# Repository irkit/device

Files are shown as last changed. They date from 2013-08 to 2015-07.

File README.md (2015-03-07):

IRKit Device
===

IRKit device and [IRKit SDK](https://github.com/irkit/ios-sdk) lets you control your home electronics from your iOS and Android devices.
IRKit device has a Infrared LED and receiver, and a WiFi module inside.
Internet connected devices can make IRKit send IR signals for you.

## Get IRKit Device

In Japan: [amazon.co.jp](http://www.amazon.co.jp/gp/product/B00H91KK26)  
World wide shipping available: [switch-science](https://international.switch-science.com/catalog/1644/)

## Schematics

Basically, it's a [Arduino Leonardo](http://arduino.cc/en/Main/ArduinoBoardLeonardo) fork with following modifications:

* added a [WiFi module](http://www.gainspan.com/gs1011mips) ( [GainSpan](http://www.gainspan.com/home) 's WiFi module ).
* added Infrared Receiver, Infrared LED and some LEDs.



## Firmware

It's basically a normal Arduino sketch.

See [IRKit.ino](https://github.com/irkit/device/blob/master/firmware/src/IRKit/IRKit.ino)

## Board

### Top



### Bottom



## Case

See [Case](https://github.com/irkit/device/tree/master/case)

## Extend it!

Following Arduino pins are pulled out for you.

* D2,D3,D4,D5,D12,TXLED
* A0,A1,A2,A3

See [IRKit.sch, eagle schematic file](https://github.com/irkit/device/blob/master/hardware/IRKit.sch) 's CN2

## How to update firmware

You can use [Arduino IDE](http://arduino.cc/en/Main/Software) to write IRKit's firmware.  
Follow this procedure (for MacOS).

1. Download, install and run [Arduino IDE](http://arduino.cc/en/Main/Software)
1. Connect IRKit using USB Micro-B cable to Mac.
1. Navigate to Arduino IDE Menu and select Tools -> Board -> "Arduino Leonardo".
1. Navigate to Arduino IDE Menu and select Tools -> Serial Port -> "/dev/tty.usbmodemXXXX".

   XXXX part should differ on your environment.

1. Download latest zip file from [IRKit device tags](https://github.com/irkit/device/releases).
1. Unzip it and open `firmware/src/IRKit/` directory.
1. Rename `version.template` to `version.c` .

   FYI. Product version is embedded here in official builds.

1. Double click `IRKit.ino` in the same directory.
1. Navigate to Arduino IDE Menu and click File -> Upload, to write into IRKit.
1. All Done!

### Example fork of IRKit firmware

[@acourreges](https://github.com/acourreges) created a branch [settings-led-cloud](https://github.com/acourreges/device/tree/settings-led-cloud/firmware) that enables you to configure:  
* Status LED behaviour (you might want to turn the LED off when the device is idle?)
* Enable/Disable cloud control (you might want IRKit not to connect to Internet?)

See [config.h](https://github.com/acourreges/device/blob/settings-led-cloud/firmware/src/IRKit/config.h) for details.

## How to get logs

IRKit logs what it's doing to USB serial, and you can use [Arduino IDE](http://arduino.cc/en/Main/Software) to see it.  
Follow this procedure (for MacOS).

1. Download, install and run [Arduino IDE](http://arduino.cc/en/Main/Software)
1. Connect IRKit using USB Micro-B cable to Mac.
1. Navigate to Arduino IDE Menu and select Tools -> Serial Port -> "/dev/tty.usbmodemXXXX".

   XXXX part should differ on your environment.

1. Navigate to Arduino IDE Menu and select Tools -> Serial Monitor.
1. Change new window's right-bottom settings to "No line ending" and "115200 baud", and close the window.
1. Reconnect IRKit and immediately start Serial Monitor again.

   This is to collect logs as soon as IRKit startups.

1. Copy and send logs to IRKit developer, thanks!

## ファームウェアアップデート方法

IRKitのファームウェアは、 [Arduino IDE](http://arduino.cc/en/Main/Software) を使って書き込むことができます。

出荷時のファームウェアバージョンによって、どのファームウェアバージョンまでアップデートできるかが変わります。  
以下の手順で現在のバージョンを確認し、対応するバージョンを使用してください。

| 現在のバージョン | 対応する最新のバージョン |
| --- | --- |
| 1.3.3以下 | [1.3.3](https://github.com/irkit/device/releases/tag/v1.3.3) |
| 1.3.4以上 | [最新](https://github.com/irkit/device/releases/latest) |

[IRKitシンプルリモコン](https://itunes.apple.com/us/app/irkit-simple-remote/id778790928?l=ja&ls=1&mt=8) を起動し、左上のボタンから設定画面を開くと、以下の画像の赤の四角のようにファームウェアバージョンを表示します。

<a href="https://www.flickr.com/photos/99687464@N00/14023119426" title="IRKit-firmware-version">IRKit-firmware-version</a>

以下がファームウェアのアップデート方法です(MacOS編)。

1. [Arduino IDE](http://arduino.cc/en/Main/Software) をダウンロードしてインストール後、起動します。
1. IRKitをUSB Micro-Bケーブルを使ってMacに接続します。
1. Arduino IDEのメニューから ツール -> マイコンボード -> "Arduino Leonardo" を選びます。
1. Arduino IDEのメニューから ツール -> シリアルポート -> "/dev/tty.usbmodemXXXX" を選びます。

   環境によってXXXXの部分やその前後が異なる場合があります。

1. ファームウェアをダウンロードし、zipファイルを解凍します。
1. 解凍したディレクトリ内にある `firmware/src/IRKit/` ディレクトリを開きます。
1. 同ディレクトリ内の `version.template` を `version.c` にリネームします。  

   参考) 製品版ではIRKitのバージョン情報をここに埋め込んでいます。

1. 同ディレクトリ内の `GSwifi.cpp` 内に埋め込んであるWi-Fiアクセスポイントのパスワードを書き換えます。  

   https://github.com/irkit/device/blob/master/firmware/src/IRKit/GSwifi.cpp#L1096  
   の `XXXXXXXXXX` を任意の文字列に書き換えてください。  
   参考) IRKitの出荷前に書き換えてから出荷しています。

1. 同ディレクトリ内の `IRKit.ino` をダブルクリックして Arduino IDE で開きます。
1. Arduino IDEのメニューから ファイル -> マイコンボードに書き込む を押してIRKitに書き込みます。
1. 完了！

### プログラムメモリについて

IRKitのマイコン ATmega32U4 はプログラムメモリを 32kB 積んでいますが、  
IRKitのファームウェアでそのほぼ全てを使用しています。

ファームウェアに改造を行い、機能追加する場合には、  
不必要な機能のログ出力や機能自体を削ってください。

[log.hの22-26行目](https://github.com/irkit/device/blob/master/firmware/src/IRKit/log.h#L22) 辺りをコメントアウトすることで、ログ出力を止めることができます。

### IRKitファームウェアのFork例

[@acourreges](https://github.com/acourreges)の[settings-led-cloud](https://github.com/acourreges/device/tree/settings-led-cloud/firmware)では、以下を変更可能にしています。  
* ステータスLEDの動作 (赤外線を送受信していない時にはLEDを消灯しておきたい??)
* クラウドとの接続を有効/無効 (IRKitをインターネットに接続せずに使いたい??)

詳しくは [config.h](https://github.com/acourreges/device/blob/settings-led-cloud/firmware/src/IRKit/config.h) を見てください。

[@shokai](https://github.com/shokai)の[tempe_sensor](https://github.com/shokai/irkit-device/compare/master...tempe_sensor)ブランチ、[sensors_json](https://github.com/shokai/irkit-device/compare/master...sensors_json)ブランチでは、  
温度センサからの入力、アナログピンの値を読み、IRKit内蔵のWebサーバからHTTP GETで取得できるようにしています。

詳しくは [IRKitのファームウェアを改造して温度センサーを追加した](http://shokai.org/blog/archives/8802) をご覧ください。

## ログ取得方法

IRKitは、USB Micro-Bを使いパソコンまたはMacに接続すると、動作ログを取得することができます。  
以下の手順でログを取得します(MacOS編)。

1. [Arduino IDE](http://arduino.cc/en/Main/Software) をダウンロードしてインストール後、起動します。
1. IRKitをUSB Micro-Bケーブルを使ってMacに接続します。
1. Arduino IDEのメニューから ツール -> シリアルポート -> "/dev/tty.usbmodemXXXX" を選びます。

   環境によってXXXXの部分やその前後が異なる場合があります。

1. Arduino IDEのメニューから ツール -> シリアルモニタ を選びます。
1. 新しく開いたウィンドウの右下の設定を "改行なし" "115200baud" に変更し、一度ウィンドウを閉じます。
1. IRKitのUSB Micro-Bケーブルを外し、再度接続した直後に、上記同様に シリアルモニタ を開きます。

   IRKit起動直後からのログを取得するためです。

1. ウィンドウに表示される文字列をコピーして開発者へメールしてください。ありがとうございます！

## License

Firmware is licensed under GPLv2 or later.  
See details in [firmware/LICENSE](https://github.com/irkit/device/blob/master/firmware/LICENSE).

Schematics are licensed under Creative Commons Attribution Share-Alike license.  
See details in [hardware/LICENSE](https://github.com/irkit/device/blob/master/hardware/LICENSE).

Case is licensed under Creative Commons Attribution NonCommercial Share-Alike license.  
See details in [case/LICENSE](https://github.com/irkit/device/blob/master/case/LICENSE).

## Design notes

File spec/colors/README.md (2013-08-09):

Full Color LED Spec
===================

## Color/State Map

* Started, Unconnected         : Green
* Connected and Authorized     : Blue
* Connected and Non Authorized : Yellow Blink
* Bluetooth -> IR              : Blue Blink
* IR -> Bluetooth              : Cyan Blink
* Timeout                      : Red

## Available Colors

* Red
* Green
* Blue
* Cyan
* Magenta
* Yellow
* White
* Off

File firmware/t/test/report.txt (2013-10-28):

* flash memory
** base 4270
#include "Arduino.h"
#include "pgmStrToRAM.h"

void setup() {
    // USB serial
    Serial.begin(115200);

    // wait for leonardo
    while ( ! Serial );
}

void loop() {
}

** overload Serial.print 6452
#include "Arduino.h"
#include "pgmStrToRAM.h"

void setup() {
    // USB serial
    Serial.begin(115200);

    // wait for leonardo
    while ( ! Serial );

    Serial.print(3);
    Serial.print(3.14);
}

void loop() {
}
** only Serial.print(float) 6398
#include "Arduino.h"
#include "pgmStrToRAM.h"

void setup() {
    // USB serial
    Serial.begin(115200);

    // wait for leonardo
    while ( ! Serial );

    Serial.print(3.14);
}

void loop() {
}
** only Serial.print(int) 4838
#include "Arduino.h"
#include "pgmStrToRAM.h"

void setup() {
    // USB serial
    Serial.begin(115200);

    // wait for leonardo
    while ( ! Serial );

    Serial.print(3);
}

void loop() {
}
** only Serial.print(char*) 4344
#include "Arduino.h"
#include "pgmStrToRAM.h"

void setup() {
    // USB serial
    Serial.begin(115200);

    // wait for leonardo
    while ( ! Serial );

    Serial.print("3");
}

void loop() {
}

** only Serial.print(char) 4296
#include "Arduino.h"
#include "pgmStrToRAM.h"

void setup() {
    // USB serial
    Serial.begin(115200);

    // wait for leonardo
    while ( ! Serial );

    Serial.print('3');
}

void loop() {
}

** sprintf 6666
#include "Arduino.h"
#include "pgmStrToRAM.h"
#include "tinyprint.h"

void setup() {
    // USB serial
    Serial.begin(115200);

    // wait for leonardo
    while ( ! Serial );

    // Serial.print("3");
    tinyprint_int(3);
}

void loop() {
}
--- tinyprint.cpp
#include "Arduino.h"
#include "tinyprint.h"
#include "pgmStrToRAM.h"

size_t tinyprint_int(int n) {
    // -32767 - 32767
    char tmp[7];
    sprintf( tmp, P("%d"), n );
    return Serial.print( tmp );
}

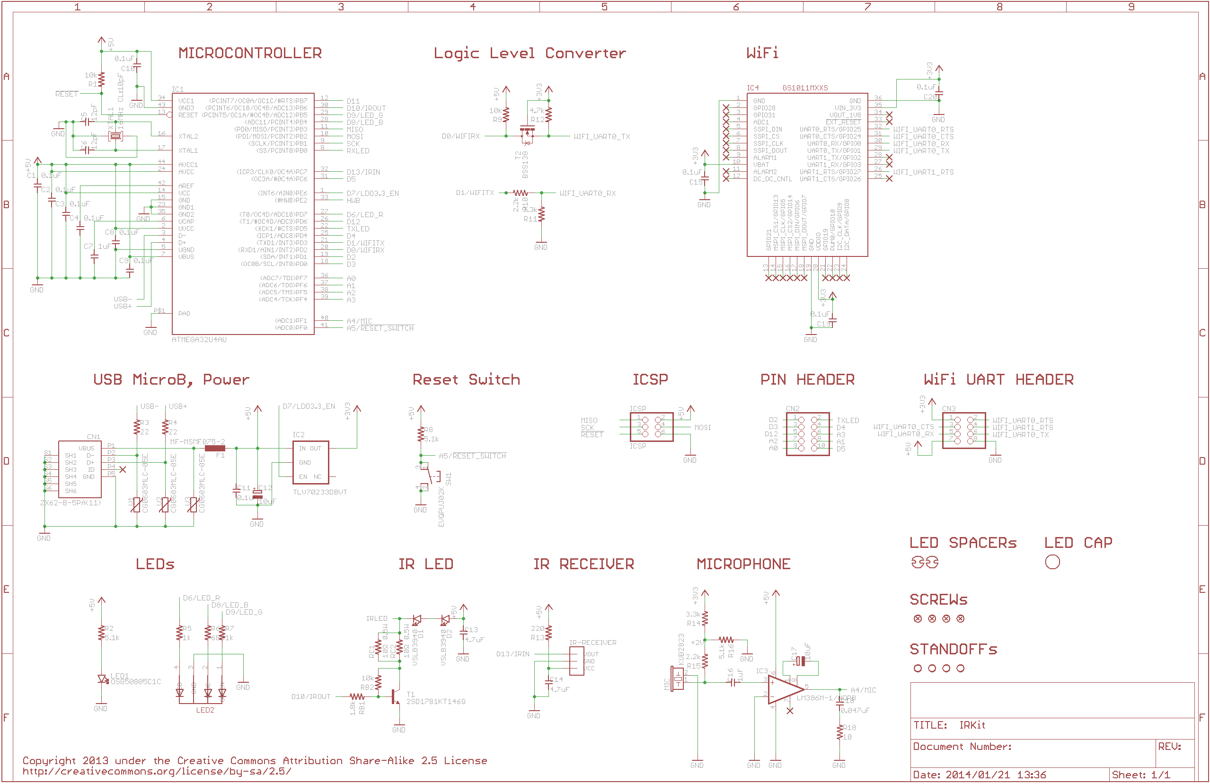
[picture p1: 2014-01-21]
hardware/schematic.png

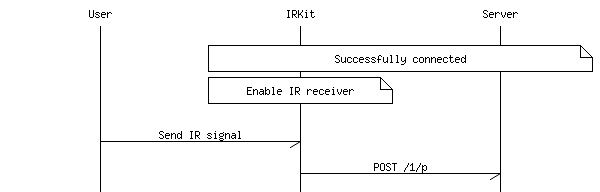
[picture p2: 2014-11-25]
spec/diagrams/ir-learn.png

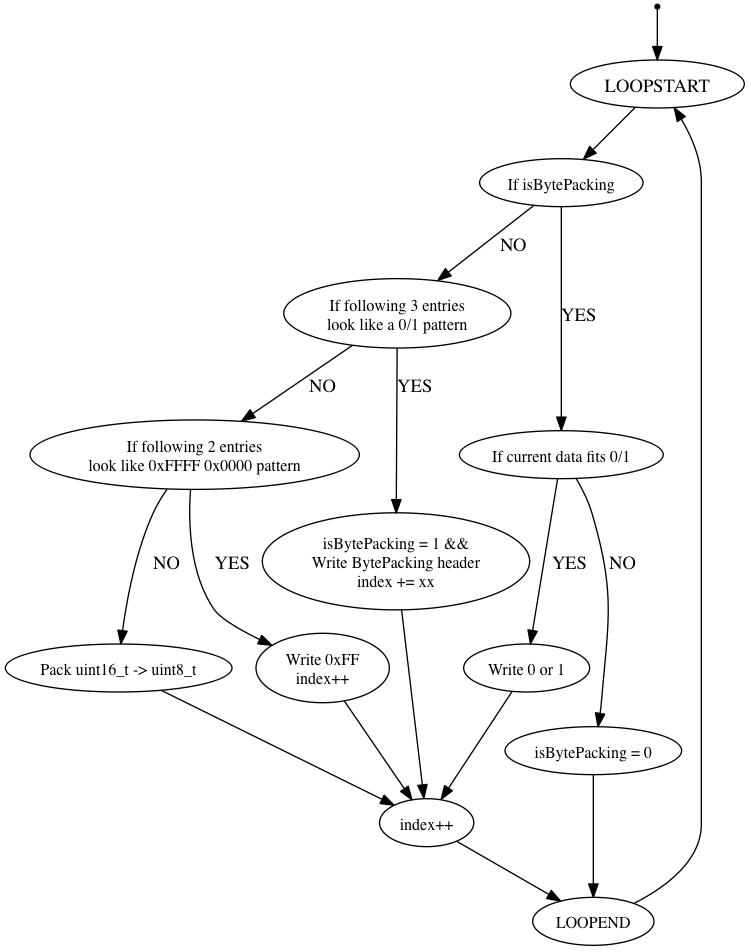
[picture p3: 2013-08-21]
spec/diagrams/packer.png

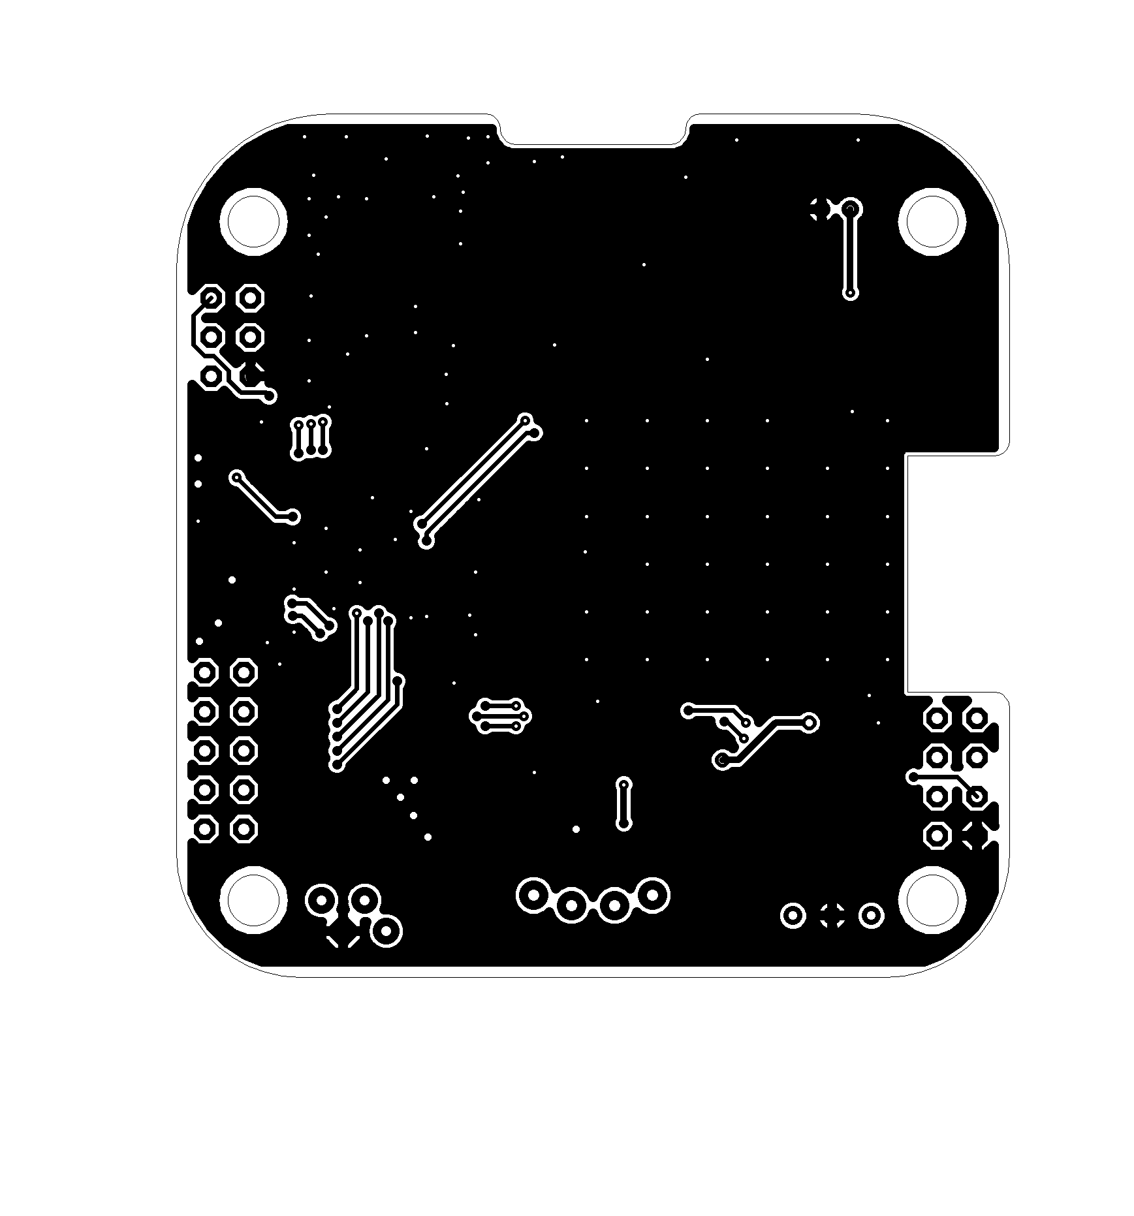
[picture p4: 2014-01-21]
hardware/bottom.png

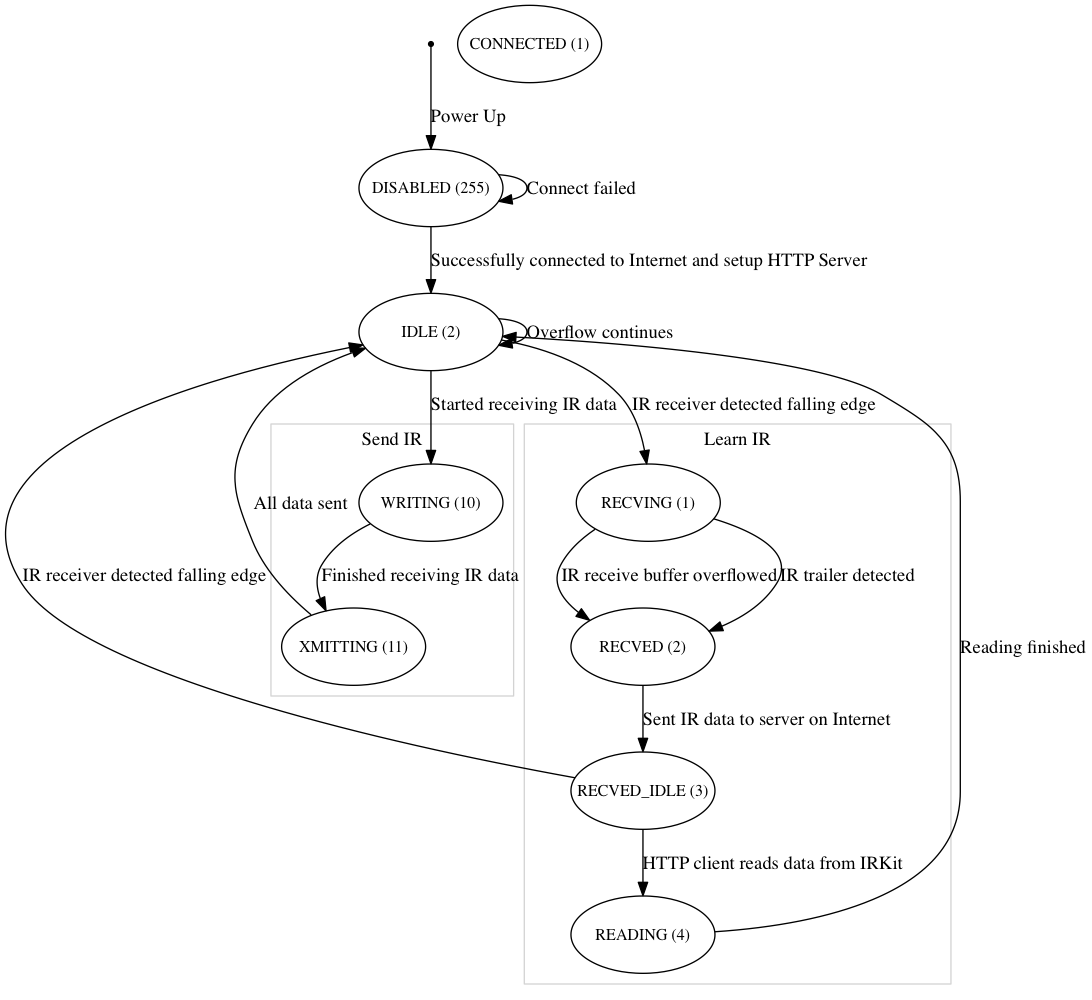
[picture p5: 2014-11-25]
spec/diagrams/ir-state.png

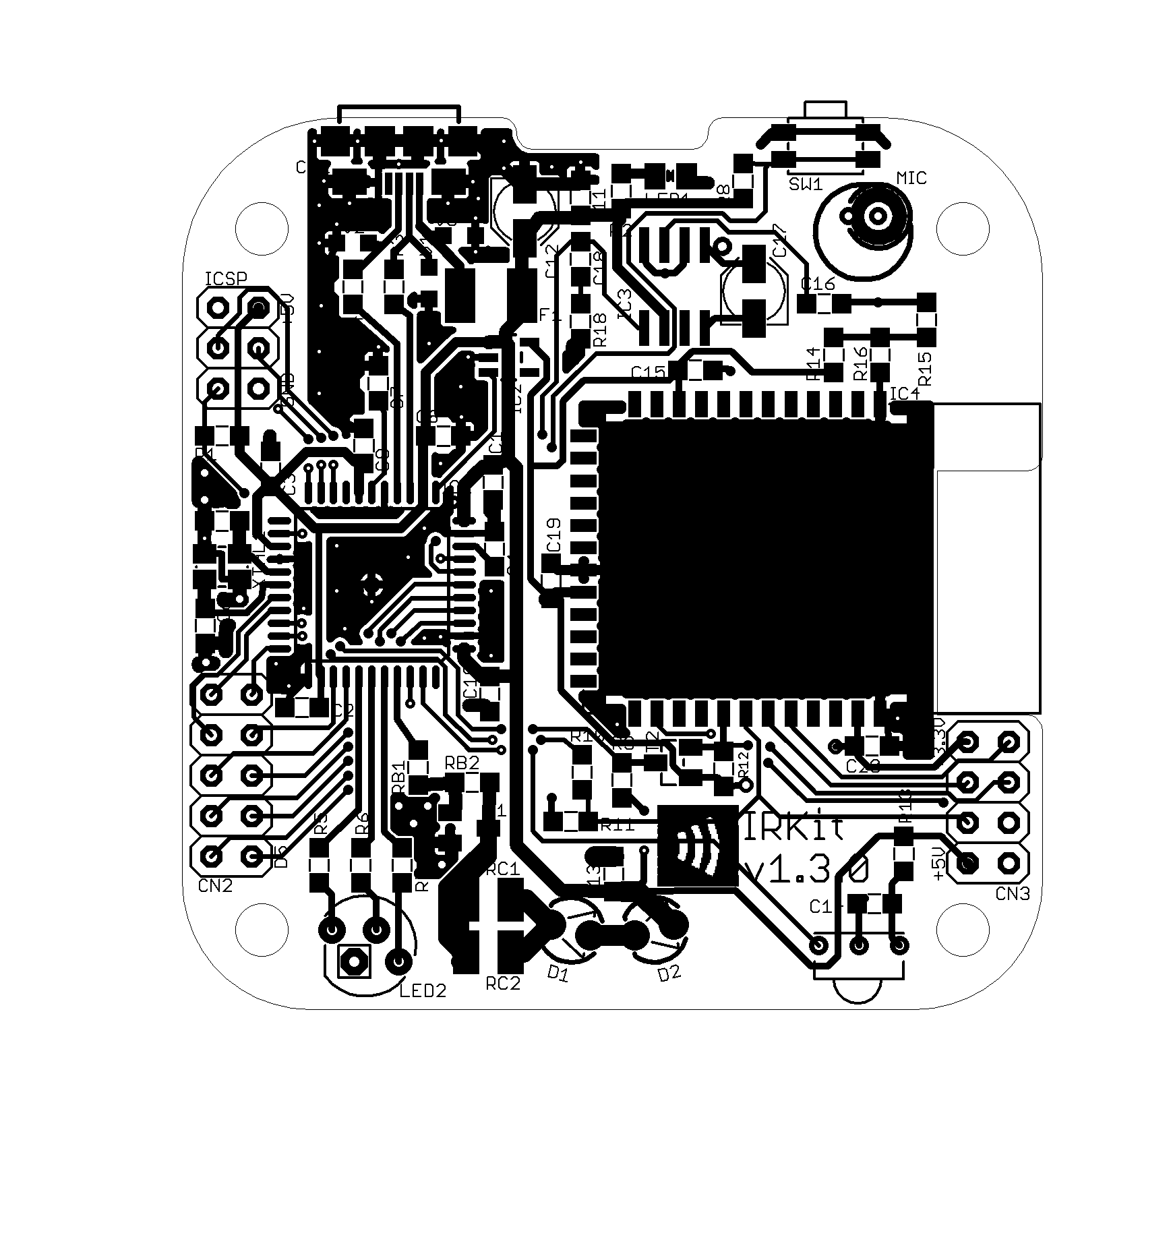
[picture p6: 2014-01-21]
hardware/top.png

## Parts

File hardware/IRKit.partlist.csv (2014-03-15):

Qty | Value | Device | Package | Parts | Description
1 |  | PINHD-2X4 | 2X04 | CN3 | PIN HEADER
1 |  | PINHD-2X5 | 2X05 | CN2 | PIN HEADER
1 | 0.047uF | CAPACITOR2012 | SMD2012 | C18 | Generic Capacitor
11 | 0.1uF | CAPACITOR2012 | SMD2012 | C1, C2, C3, C4, C8, C9, C10, C11, C15, C19, C20 | Generic Capacitor
1 | 1.8k | RESISTOR-US2012 | SMD2012 | RB1 | Generic Registor
1 | 10 | RESISTOR-US2012 | SMD2012 | R18 | Generic Registor
3 | 10k | RESISTOR-US2012 | SMD2012 | R1, R9, RB2 | Generic Registor
2 | 10uF | CAPACITOR-POLPANASONIC_B | PANASONIC_B | C12, C17 | Generic Capacitor with Polarity
2 | 10Ω 0.5W | R3225 | 3225 | RC1, RC2 | RESISTOR
2 | 12pF | CAPACITOR2012 | SMD2012 | C5, C6 | Generic Capacitor
1 | 16MHz CL:10pF | CRYSTAL-3.2-2.5 | CRYSTAL-3.2-2.5 | XTAL1
2 | 1uF | CAPACITOR2012 | SMD2012 | C7, C16 | Generic Capacitor
4 | 2.2k | RESISTOR-US2012 | SMD2012 | R2, R6, R10, R15 | Generic Registor
2 | 22 | RESISTOR-US2012 | SMD2012 | R3, R4 | Generic Registor
1 | 220 | RESISTOR-US2012 | SMD2012 | R13 | Generic Registor
1 | 254-ECM6044-RO | MICELECTRET_SMD | MIC_SMD_4MM | MIC | Omni-directional electret condenser microphone.
1 | 2SD1781KT146Q | MMUN2211LT1-NPN-SC59-BEC | SC59-BEC | T1 | NPN Transistror
4 | 3.3k | RESISTOR-US2012 | SMD2012 | R5, R7, R11, R14 | Generic Registor
1 | 4.7k | RESISTOR-US2012 | SMD2012 | R12 | Generic Registor
2 | 4.7uF | CAPACITOR2012 | SMD2012 | C13, C14 | Generic Capacitor
2 | 5.1k | RESISTOR-US2012 | SMD2012 | R8, R16 | Generic Registor
1 | 5MMRGBLED | 5MMRGBLED | LED5MMRGB | LED2
1 | ATMEGA32U4AU | ATMEGA32U4AU | TQFP44-PAD | IC1
1 | BSS138 | BSS138 | SOT23 | T2
3 | CG0603MLC-05E | VARISTORCN0603 | CT/CN0603 | V1, V2, V3 | VARISTOR
1 | EVQPUJ02K | TACTILE-SWITCHEVQPUJ02K | TACTILE-SWITCH-EVQPUJ02K | SW1 | TACTILE SWITCH
1 | GS1011MXXS | GS1011MXXS | GS1011MXXS | IC4
1 | ICSP | PINHD-2X3 | 2X03 | ICSP | PIN HEADER
1 | LED-CAP | LED-CAP | LED-CAP | LEDCAP1
2 | LK-5 | LED-SPACER-LK | LED-SPACER-LK | SP1, SP2
1 | LM386M-1/NOPB | LM386M-1 | SO08 | IC3 | Low Voltage Audio Power Amplifier
1 | MF-MSMF075-2 | L-EUL1812 | L1812 | F1 | INDUCTOR, European symbol
1 | PG1112H-TR | LED-2012 | LED2012 | LED1 | Through-hole LED
1 | PL-IRM2161 | PL-IRM2161 | IR-RECEIVER | IR-RECEIVER | PL-IRM2161-XD1
4 | STAND-OFF | STAND-OFF | STAND-OFF | STANDOFF1, STANDOFF2, STANDOFF3, STANDOFF4 | #4 Stand Off
1 | TLV70233DBVT | TLV702XXSMD | SOT23-5 | IC2 | TLV702xx
2 | VSLB3940 | LED-3MM | LED3MM | D1, D2 | Through-hole LED
1 | ZX62-B-5PA(11) | USB-CONNECTORMICROB | USB-MICROB | CN1
4 | flat-head M3 self-tapping | SCREW | SCREW-M3 | SCREW1, SCREW2, SCREW3, SCREW4

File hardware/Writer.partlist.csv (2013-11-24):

Qty | Value | Device | Package | Parts | Description
5 | 1k | RESISTOR-US2012 | SMD2012 | R2, R4, R5, R6, R7 | Generic Registor
2 | 5.1k | RESISTOR-US2012 | SMD2012 | R1, R3 | Generic Registor
1 | IRKit ICSP | PINHD-2X3 | 2X03 | ICSP | PIN HEADER
1 | IRKit Wifi | PINHD-2X4 | 2X04 | CN1 | PIN HEADER
1 | JAPANINO-SLIM | JAPANINO-SLIM | JAPANINO-SLIM | IC1
2 | OSG50805C1C | LED-2012 | LED2012 | LED1, LED2 | Through-hole LED
1 | SLIDE-SWITCH4/2 | SLIDE-SWITCH4/2 | SLIDE-SWITCH-MCS421N | SW2
1 | SS12D01G4 | SLIDE-SWITCH1/2 | SS12D01G4 | SW1 | SLIDING SWITCH
4 | STAND-OFF | STAND-OFF | STAND-OFF | STANDOFF1, STANDOFF2, STANDOFF3, STANDOFF4 | #4 Stand Off
1 | TTL-232R-3V3 | PINHD-1X6/90 | 1X06/90 | JP1 | PIN HEADER

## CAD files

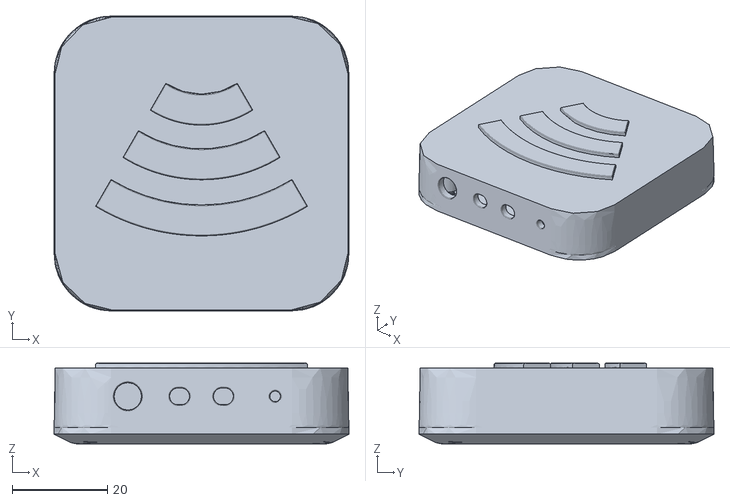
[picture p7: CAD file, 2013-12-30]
case/IRKit.stl
62.1 x 62.1 x 17.0

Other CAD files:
case/FactoryJig.3dm
case/IRKit.3dm

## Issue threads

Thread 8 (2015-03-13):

Wired devices

barrettj, 2015-03-13:
Despite joining my wifi, it doesn't appear any of my wired devices can access the local API - is this intentional or am I doing something wrong?  These wired devices can get a ping response, but not from the http server.

All of my devices that are connected to the wifi network can get a response.

barrettj, 2015-03-15:
Nevermind, it seems to be working most of the time now.  Occasionally I'll get back an empty response from the server, but usually it works.

Closed 2015-04-06.

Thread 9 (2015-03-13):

Errors trying to compile firmware

barrettj, 2015-03-13:
When trying to compile the firmware via the instructions in the readme I get the following:

```
Arduino: 1.6.1 (Mac OS X), Board: "Arduino Leonardo"

from GSwifi.cpp:25:
pgmStrToRAM.h:22:32: error: invalid conversion from 'const char*' to 'char*' [-fpermissive]
 #define P(s)       pgmStrToRAM(PSTR(s),0)
                                ^
GSwifi.cpp:779:31: note: in expansion of macro 'P'
                  strncmp(buf, P("Serial2WiFi APP"), 15) == 0) {
                               ^
In file included from GSwifi.cpp:26:0:
pgmStrToRAM.h:29:7: error:   initializing argument 1 of 'char* pgmStrToRAM(char*, uint8_t)' [-fpermissive]
 char *pgmStrToRAM(PROGMEM char *theString, uint8_t index);
       ^
In file included from GSwifi.cpp:35:0:
GSwifi.cpp: In member function 'void GSwifi::parseCmdResponse(char*)':
pgmStrToRAM.h:22:32: error: invalid conversion from 'const char*' to 'char*' [-fpermissive]
 #define P(s)       pgmStrToRAM(PSTR(s),0)
                                ^
log.h:45:43: note: in definition of macro 'GSLOG_PRINT'
 # define GSLOG_PRINT(a)      Serial.print(a)
                                           ^
GSwifi.cpp:795:17: note: in expansion of macro 'P'
     GSLOG_PRINT(P("c< ")); GSLOG_PRINTLN(buf);
                 ^
In file included from GSwifi.cpp:26:0:
pgmStrToRAM.h:29:7: error:   initializing argument 1 of 'char* pgmStrToRAM(char*, uint8_t)' [-fpermissive]
 char *pgmStrToRAM(PROGMEM char *theString, uint8_t index);
       ^
In file included from /Applications/Arduino.app/Contents/Resources/Java/hardware/arduino/avr/cores/arduino/Arduino.h:28:0,
                 from GSwifi.cpp:25:
pgmStrToRAM.h:22:32: error: invalid conversion from 'const char*' to 'char*' [-fpermissive]
 #define P(s)       pgmStrToRAM(PSTR(s),0)
                                ^
GSwifi.cpp:809:26: note: in expansion of macro 'P'
         if (strncmp(buf, P("CONNECT "), 8) == 0 && buf[9] == 0) {
                          ^
In file included from GSwifi.cpp:26:0:
pgmStrToRAM.h:29:7: error:   initializing argument 1 of 'char* pgmStrToRAM(char*, uint8_t)' [-fpermissive]
 char *pgmStrToRAM(PROGMEM char *theString, uint8_t index);
       ^
In file included from /Applications/Arduino.app/Contents/Resources/Java/hardware/arduino/avr/cores/arduino/Arduino.h:28:0,
                 from GSwifi.cpp:25:
pgmStrToRAM.h:22:32: error: invalid conversion from 'const char*' to 'char*' [-fpermissive]
 #define P(s)       pgmStrToRAM(PSTR(s),0)
                                ^
GSwifi.cpp:832:52: note: in expansion of macro 'P'
         if (gs_response_lines_ == 0 && strstr(buf, P("SubNet"))) {
                                                    ^
In file included from GSwifi.cpp:26:0:
pgmStrToRAM.h:29:7: error:   initializing argument 1 of 'char* pgmStrToRAM(char*, uint8_t)' [-fpermissive]
 char *pgmStrToRAM(PROGMEM char *theString, uint8_t index);
       ^
In file included from /Applications/Arduino.app/Contents/Resources/Java/hardware/arduino/avr/cores/arduino/Arduino.h:28:0,
                 from GSwifi.cpp:25:
pgmStrToRAM.h:22:32: error: invalid conversion from 'const char*' to 'char*' [-fpermissive]
 #define P(s)       pgmStrToRAM(PSTR(s),0)
                                ^
GSwifi.cpp:840:26: note: in expansion of macro 'P'
         if (strncmp(buf, P("IP:"), 3) == 0) {
                          ^
In file included from GSwifi.cpp:26:0:
pgmStrToRAM.h:29:7: error:   initializing argument 1 of 'char* pgmStrToRAM(char*, uint8_t)' [-fpermissive]
 char *pgmStrToRAM(PROGMEM char *theString, uint8_t index);
       ^
In file included from GSwifi.cpp:35:0:
GSwifi.cpp: In member function 'void GSwifi::command(const char*, GSwifi::GSCOMMANDMODE, uint8_t)':
pgmStrToRAM.h:22:32: error: invalid conversion from 'const char*' to 'char*' [-fpermissive]
 #define P(s)       pgmStrToRAM(PSTR(s),0)
                                ^
log.h:45:43: note: in definition of macro 'GSLOG_PRINT'
 # define GSLOG_PRINT(a)      Serial.print(a)
                                           ^
GSwifi.cpp:903:17: note: in expansion of macro 'P'
     GSLOG_PRINT(P("c> "));
                 ^
In file included from GSwifi.cpp:26:0:
pgmStrToRAM.h:29:7: error:   initializing argument 1 of 'char* pgmStrToRAM(char*, uint8_t)' [-fpermissive]
 char *pgmStrToRAM(PROGMEM char *theString, uint8_t index);
       ^
In file included from GSwifi.cpp:35:0:
GSwifi.cpp: In member function 'void GSwifi::escape(const char*, uint8_t)':
pgmStrToRAM.h:22:32: error: invalid conversion from 'const char*' to 'char*' [-fpermissive]
 #define P(s)       pgmStrToRAM(PSTR(s),0)
                                ^
log.h:45:43: note: in definition of macro 'GSLOG_PRINT'
 # define GSLOG_PRINT(a)      Serial.print(a)
                                           ^
GSwifi.cpp:920:17: note: in expansion of macro 'P'
     GSLOG_PRINT(P("e> "));
                 ^
In file included from GSwifi.cpp:26:0:
pgmStrToRAM.h:29:7: error:   initializing argument 1 of 'char* pgmStrToRAM(char*, uint8_t)' [-fpermissive]
 char *pgmStrToRAM(PROGMEM char *theString, uint8_t index);
       ^
In file included from /Applications/Arduino.app/Contents/Resources/Java/hardware/arduino/avr/cores/arduino/Arduino.h:28:0,
                 from GSwifi.cpp:25:
GSwifi.cpp: In member function 'int8_t GSwifi::join(GSSECURITY, const char*, const char*, int, char*)':
pgmStrToRAM.h:23:32: error: invalid conversion from 'const char*' to 'char*' [-fpermissive]
 #define PB(s,i)    pgmStrToRAM(PSTR(s),i)
                                ^
GSwifi.cpp:996:13: note: in expansion of macro 'PB'
     command(PB("AT+WM=0",1), GSCOMMANDMODE_NORMAL);
             ^
In file included from GSwifi.cpp:26:0:
pgmStrToRAM.h:29:7: error:   initializing argument 1 of 'char* pgmStrToRAM(char*, uint8_t)' [-fpermissive]
 char *pgmStrToRAM(PROGMEM char *theString, uint8_t index);
       ^
In file included from /Applications/Arduino.app/Contents/Resources/Java/hardware/arduino/avr/cores/arduino/Arduino.h:28:0,
                 from GSwifi.cpp:25:
pgmStrToRAM.h:23:32: error: invalid conversion from 'const char*' to 'char*' [-fpermissive]
 #define PB(s,i)    pgmStrToRAM(PSTR(s),i)
                                ^
GSwifi.cpp:999:11: note: in expansion of macro 'PB'
     cmd = PB("AT+NDHCP=1,%",1);
           ^
In file included from GSwifi.cpp:26:0:
pgmStrToRAM.h:29:7: error:   initializing argument 1 of 'char* pgmStrToRAM(char*, uint8_t)' [-fpermissive]
 char *pgmStrToRAM(PROGMEM char *theString, uint8_t index);
       ^
In file included from /Applications/Arduino.app/Contents/Resources/Java/hardware/arduino/avr/cores/arduino/Arduino.h:28:0,
                 from GSwifi.cpp:25:
pgmStrToRAM.h:23:32: error: invalid conversion from 'const char*' to 'char*' [-fpermissive]
 #define PB(s,i)    pgmStrToRAM(PSTR(s),i)
                                ^
GSwifi.cpp:1007:17: note: in expansion of macro 'PB'
         command(PB("AT+WSEC=0",1), GSCOMMANDMODE_NORMAL);
                 ^
In file included from GSwifi.cpp:26:0:
pgmStrToRAM.h:29:7: error:   initializing argument 1 of 'char* pgmStrToRAM(char*, uint8_t)' [-fpermissive]
 char *pgmStrToRAM(PROGMEM char *theString, uint8_t index);
       ^
In file included from /Applications/Arduino.app/Contents/Resources/Java/hardware/arduino/avr/cores/arduino/Arduino.h:28:0,
                 from GSwifi.cpp:25:
pgmStrToRAM.h:23:32: error: invalid conversion from 'const char*' to 'char*' [-fpermissive]
 #define PB(s,i)    pgmStrToRAM(PSTR(s),i)
                                ^
GSwifi.cpp:1009:15: note: in expansion of macro 'PB'
         cmd = PB("AT+WAUTH=%",1);
               ^
In file included from GSwifi.cpp:26:0:
pgmStrToRAM.h:29:7: error:   initializing argument 1 of 'char* pgmStrToRAM(char*, uint8_t)' [-fpermissive]
 char *pgmStrToRAM(PROGMEM char *theString, uint8_t index);
       ^
In file included from /Applications/Arduino.app/Contents/Resources/Java/hardware/arduino/avr/cores/arduino/Arduino.h:28:0,
                 from GSwifi.cpp:25:
pgmStrToRAM.h:23:32: error: invalid conversion from 'const char*' to 'char*' [-fpermissive]
 #define PB(s,i)    pgmStrToRAM(PSTR(s),i)
                                ^
GSwifi.cpp:1014:19: note: in expansion of macro 'PB'
             cmd = PB("AT+WWEP1=%",1);
                   ^
In file included from GSwifi.cpp:26:0:
pgmStrToRAM.h:29:7: error:   initializing argument 1 of 'char* pgmStrToRAM(char*, uint8_t)' [-fpermissive]
 char *pgmStrToRAM(PROGMEM char *theString, uint8_t index);
       ^
In file included from /Applications/Arduino.app/Contents/Resources/Java/hardware/arduino/avr/cores/arduino/Arduino.h:28:0,
                 from GSwifi.cpp:25:
pgmStrToRAM.h:23:32: error: invalid conversion from 'const char*' to 'char*' [-fpermissive]
 #define PB(s,i)    pgmStrToRAM(PSTR(s),i)
                                ^
GSwifi.cpp:1018:15: note: in expansion of macro 'PB'
         cmd = PB("AT+WA=%",1);
               ^
In file included from GSwifi.cpp:26:0:
pgmStrToRAM.h:29:7: error:   initializing argument 1 of 'char* pgmStrToRAM(char*, uint8_t)' [-fpermissive]
 char *pgmStrToRAM(PROGMEM char *theString, uint8_t index);
       ^
In file included from /Applications/Arduino.app/Contents/Resources/Java/hardware/arduino/avr/cores/arduino/Arduino.h:28:0,
                 from GSwifi.cpp:25:
pgmStrToRAM.h:23:32: error: invalid conversion from 'const char*' to 'char*' [-fpermissive]
 #define PB(s,i)    pgmStrToRAM(PSTR(s),i)
                                ^
GSwifi.cpp:1029:17: note: in expansion of macro 'PB'
         command(PB("AT+WAUTH=0",1), GSCOMMANDMODE_NORMAL);
                 ^
In file included from GSwifi.cpp:26:0:
pgmStrToRAM.h:29:7: error:   initializing argument 1 of 'char* pgmStrToRAM(char*, uint8_t)' [-fpermissive]
 char *pgmStrToRAM(PROGMEM char *theString, uint8_t index);
       ^
In file included from /Applications/Arduino.app/Contents/Resources/Java/hardware/arduino/avr/cores/arduino/Arduino.h:28:0,
                 from GSwifi.cpp:25:
pgmStrToRAM.h:23:32: error: invalid conversion from 'const char*' to 'char*' [-fpermissive]
 #define PB(s,i)    pgmStrToRAM(PSTR(s),i)
                                ^
GSwifi.cpp:1031:15: note: in expansion of macro 'PB'
         cmd = PB("AT+WWPA=%",1);
               ^
In file included from GSwifi.cpp:26:0:
pgmStrToRAM.h:29:7: error:   initializing argument 1 of 'char* pgmStrToRAM(char*, uint8_t)' [-fpermissive]
 char *pgmStrToRAM(PROGMEM char *theString, uint8_t index);
       ^
In file included from /Applications/Arduino.app/Contents/Resources/Java/hardware/arduino/avr/cores/arduino/Arduino.h:28:0,
                 from GSwifi.cpp:25:
pgmStrToRAM.h:23:32: error: invalid conversion from 'const char*' to 'char*' [-fpermissive]
 #define PB(s,i)    pgmStrToRAM(PSTR(s),i)
                                ^
GSwifi.cpp:1035:15: note: in expansion of macro 'PB'
         cmd = PB("AT+WA=%",1);
               ^
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
barrettj, 2015-03-13:
It seems to work if I use version 1.0.6 which is available under the "old releases" section, but not if I use 1.6.0 which is the one on the page linked in the readme.

mash, 2015-03-14:
It seems the compiler option changed in Arduino1.6.1, I'll try to fix this.

suisho, 2015-04-04:
I got same issue

mash, 2015-04-06:
Latest push compiles fine on Arduino 1.6.3.
1.6.3's gcc generates code which uses less ROM but a little bit more RAM than 1.0.5 did.
I recommend 1.0.5 if you're just updating to the newest firmware.

```
% /Applications/Arduino.app/Contents/Java/hardware/tools/avr/bin/avr-size -A 1.0.5/firmware.elf
1.0.5/firmware.elf  :
section             size      addr
.data                872   8388864
.text              27578         0
.bss                1366   8389736

% /Applications/Arduino.app/Contents/Java/hardware/tools/avr/bin/avr-size -A 1.6.3/firmware.elf
1.6.3/firmware.elf  :
section            size      addr
.data               876   8388864
.text             26194         0
.bss               1364   8389740
```

Closed 2015-09-11.

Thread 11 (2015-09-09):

IRKit's security issue in v1, v2 firmware

mash, 2015-09-09:
Since IRKit is open source, and it's APIs are officially public, many people have tried to use IRKit and send IR signals in their own preferred way.

Ex: send IR signals from terminal using curl commands, or sending IR signals from a custom designed web site.

Whereas the feature to enable sending IR signals from a web site, can be abused to send IR signals when IRKit owners don't intend to.
When following conditions are all met, an attacker can send arbitrary IR signals from IRKit.

* IRKit's owner is using a computer connected to the same home network with IRKit
* IRKit's owner opens a web site, created by the attacker
* IRKit is setup successfully
* Attacker can guess IRKit's internal IP address in the home network

The person who discovered this problem is me, and I haven't heard any real attacks utilizing this problem.

IRKits having this problem are sold before Aug, 2015. IRKits sold after that already have updated firmware written. Check IRKit's version using the official iPhone and Android app, and update IRKit's firmware if the version was below `v3.0.0.gxxxxx`. Please update if the version was something like `v1.x.x.gxxxxx` or `v2.x.x.gxxxxx`.

<a data-flickr-embed="true" data-header="false" data-footer="false" data-context="false"  href="https://www.flickr.com/photos/99687464@N00/14023119426" title="IRKit-firmware-version">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</a><script async src="//embedr.flickr.com/assets/client-code.js" charset="utf-8"></script>

To update IRKit's firmware, use [IRKit Updater](https://github.com/irkit/updater), an Mac, Windows compatible application solely to update IRKit's firmware (IRKit's internal software).

IRKit Updater works on following environments.
- Mac OSX 10.8 and later
- Windows 7 and later

Please go through following steps to use IRKit Updater.

1. [Download latest IRKit Updater](https://github.com/irkit/updater/releases/latest)
1. Extract zip file
1. Connect IRKit to computer via USB cable
1. Install IRKit's driver (IRKit.inf is located inside the extracted directory) if you're on Windows environment
1. Run IRKit Updater
   If you're using Mac, double click `IRKit Updater.app`, if you're using Windows, double click `IRKit Updater.exe`
1. Click on `Update` button
<a data-flickr-embed="true" data-header="false" data-footer="false" data-context="false"  href="https://www.flickr.com/photos/maaash/20891451740/in/dateposted/" title="スクリーンショット 2015-09-02 15.54.33">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</a><script async src="//embedr.flickr.com/assets/client-code.js" charset="utf-8"></script>
1. You'll see detailed progress in Log area. If you see following screen, update is successfully finished.
<a data-flickr-embed="true" data-header="false" data-footer="false" data-context="false"  href="https://www.flickr.com/photos/maaash/21053384776/in/dateposted/" title="スクリーンショット 2015-09-02 16.01.47">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</a><script async src="//embedr.flickr.com/assets/client-code.js" charset="utf-8"></script>
1. If something went wrong, please follow the instructions shown in the app and retry, or click on the `Copy` button on the right-top of the Log area, and send an email to support@getirkit.com

This firmware update is a non compatible change in IRKit's [Device HTTP API](http://getirkit.com/en/#IRKit-Device-API) (IRKit's own HTTP server's API). Apps or scripts using Device HTTP API might not work after the update.

Following IRKit compatible apps are already updated. Please update to the latest version from AppStore or Google Play Store.

* Official iPhone app IRKit Simple Remote
* Official Android app IRKit Simple Remote
* iPhone app NK Remote
* iPhone app Geo IR
* iPhone app Geo command

If you wrote your own app or script which utilizes IRKit Device HTTP API, change your code in the following way.

* If you are NOT using a browser to send requests to IRKit, add a `X-Requested-With: curl` custom header to your request.
* If you are using a browser to send requests to IRKit, some endpoints have been disabled due to this update.
  [POST /messages](http://getirkit.com/en/#IRKit-Device-POST-messages) API is only available, if you add the IRKit's Wi-Fi access point password into IR signal JSON representation, and if you don't append the `X-Requested-With` custom header.
  ```
  {"format":"raw","freq":38,"data":[18031,8755,...snip...4400,1190],"password":"XXXXXXXXXX"}
  ```

  If you already have JSON representation of IR signals already learned, you can send it as written above. To learn IR signals, use [IRKit Internet HTTP API](http://getirkit.com/en/#IRKit-Internet-API)

If you have a public repository of IRKit related code on github, I might occasionally visit and send a pull request.

Closed 2015-09-11.

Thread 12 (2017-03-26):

firmwareがコンパイルエラーになる

kossie, 2017-03-26:
LEDを消すことを行おうとして、ファームウェアの書き換えを行うとv3.0.0をダウンロードしました。
初めに何も変更せずにコンパイルを実行しようとしたところ以下のエラーが発生しました。
初心者なので初歩的なところの問題だと思うのですが、どうすればいいでしょうか？

OS:Mac OSX 10.12.13
arudino IDE: 1.0.6
```
This report would have more information with
  "Show verbose output during compilation"
  enabled in File > Preferences.
Arduino: 1.0.6 (Mac OS X), Board: "Arduino Uno"
timer.c: In function 'timer_init':
timer.c:45: error: 'TCCR4B' undeclared (first use in this function)
timer.c:45: error: (Each undeclared identifier is reported only once
timer.c:45: error: for each function it appears in.)
timer.c:46: error: 'TCCR4A' undeclared (first use in this function)
timer.c:47: error: 'TCCR4C' undeclared (first use in this function)
timer.c:48: error: 'TCCR4D' undeclared (first use in this function)
timer.c:49: error: 'TCCR4E' undeclared (first use in this function)
timer.c:50: error: 'CS43' undeclared (first use in this function)
timer.c:50: error: 'PSR4' undeclared (first use in this function)
timer.c:53: error: 'OCR4C' undeclared (first use in this function)
timer.c: In function 'timer_start':
timer.c:59: error: 'TIFR4' undeclared (first use in this function)
timer.c:59: error: 'TOV4' undeclared (first use in this function)
timer.c:60: error: 'TCNT4' undeclared (first use in this function)
timer.c:61: error: 'TIMSK4' undeclared (first use in this function)
timer.c:61: error: 'TOIE4' undeclared (first use in this function)
timer.c: In function 'timer_stop':
timer.c:65: error: 'TIMSK4' undeclared (first use in this function)
```

mash, 2017-03-26:
https://github.com/irkit/device#ファームウェアアップデート方法
こちらをご確認ください

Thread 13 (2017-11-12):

First HTTP request hangs device

kevingriffin, 2017-11-12:
It seems that both of my IRKit units will hang after receiving their first HTTP request (like `GET /messages`). Looking at the serial monitor in the Arduino IDE, the request is acknowledged but never answered. The unit seems to get a little warm during this time, suggesting some kind of spinning behavior.

mash, 2017-11-13:
Can you write the exact curl command line and curl version that replicates the problem, so that I can try with a unit in hand?

kevingriffin, 2017-11-13:
Sure:

`curl http://<ip-address>/messages -H "X-Requested-With: curl"`

I've been experimenting with the firmware and have found that returning earlier around https://github.com/irkit/device/blob/f80e8374bb57c3db1eb42a5dc002524c0c031eae/firmware/src/IRKit/GSwifi.cpp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 will cause a crash instead of the unit becoming unresponsive, so I'm iterating around there trying to find the cause.

mash, 2017-11-13:
That curl line is so normal that shouldn't be a common problem for all 12k units shipped so far.
Can you check:

* If AC adaptor and USB cable are fine. I often hear power instability causing IRKit's instability.
* Try another Wi-Fi accesspoint

?

kevingriffin, 2017-11-13:
Sure, I'll try to change these things tonight. One thing to add—I have two units, and they both started behaving this way suddenly a few weeks ago.

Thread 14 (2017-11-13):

Can the power LED be optional?

domier, 2017-11-13:
Is it possible to update the firmware to allow us to disable the status LED?  It's very bright at night. Ideally, the LED would be on during power-up and wifi-connection, but then turn off once connected successfully.

mash, 2017-11-13:
see https://github.com/irkit/device/pull/6 and try by yourself if you wish

domier, 2017-12-17:
I tried flashing his firmware to the irkit following the instructions in the readme, but got the following error:

Arduino: 1.8.5 (Linux), Board: "Arduino Leonardo"

/home/xx/Downloads/arduino-1.8.5-linux64/arduino-1.8.5/arduino-builder -dump-prefs -logger=machine -hardware /home/xx/Downloads/arduino-1.8.5-linux64/arduino-1.8.5/hardware -tools /home/xx/Downloads/arduino-1.8.5-linux64/arduino-1.8.5/tools-builder -tools /home/xx/Downloads/arduino-1.8.5-linux64/arduino-1.8.5/hardware/tools/avr -built-in-libraries /home/xx/Downloads/arduino-1.8.5-linux64/arduino-1.8.5/libraries -libraries /home/xx/Arduino/libraries -fqbn=arduino:avr:leonardo -ide-version=10805 -build-path /tmp/arduino_build_936373 -warnings=none -build-cache /tmp/arduino_cache_98570 -prefs=build.warn_data_percentage=75 -prefs=runtime.tools.avrdude.path=/home/xx/Downloads/arduino-1.8.5-linux64/arduino-1.8.5/hardware/tools/avr -prefs=runtime.tools.arduinoOTA.path=/home/xx/Downloads/arduino-1.8.5-linux64/arduino-1.8.5/hardware/tools/avr -prefs=runtime.tools.avr-gcc.path=/home/xx/Downloads/arduino-1.8.5-linux64/arduino-1.8.5/hardware/tools/avr -verbose /home/xx/Downloads/irkit firmware/device-settings-led-cloud/firmware/src/IRKit/IRKit.ino
/home/xx/Downloads/arduino-1.8.5-linux64/arduino-1.8.5/arduino-builder -compile -logger=machine -hardware /home/xx/Downloads/arduino-1.8.5-linux64/arduino-1.8.5/hardware -tools /home/xx/Downloads/arduino-1.8.5-linux64/arduino-1.8.5/tools-builder -tools /home/xx/Downloads/arduino-1.8.5-linux64/arduino-1.8.5/hardware/tools/avr -built-in-libraries /home/xx/Downloads/arduino-1.8.5-linux64/arduino-1.8.5/libraries -libraries /home/xx/Arduino/libraries -fqbn=arduino:avr:leonardo -ide-version=10805 -build-path /tmp/arduino_build_936373 -warnings=none -build-cache /tmp/arduino_cache_98570 -prefs=build.warn_data_percentage=75 -prefs=runtime.tools.avrdude.path=/home/xx/Downloads/arduino-1.8.5-linux64/arduino-1.8.5/hardware/tools/avr -prefs=runtime.tools.arduinoOTA.path=/home/xx/Downloads/arduino-1.8.5-linux64/arduino-1.8.5/hardware/tools/avr -prefs=runtime.tools.avr-gcc.path=/home/xx/Downloads/arduino-1.8.5-linux64/arduino-1.8.5/hardware/tools/avr -verbose /home/xx/Downloads/irkit firmware/device-settings-led-cloud/firmware/src/IRKit/IRKit.ino
Using board 'leonardo' from platform in folder: /home/xx/Downloads/arduino-1.8.5-linux64/arduino-1.8.5/hardware/arduino/avr
Using core 'arduino' from platform in folder: /home/xx/Downloads/arduino-1.8.5-linux64/arduino-1.8.5/hardware/arduino/avr
Build options changed, rebuilding all
Detecting libraries used...
"/home/xx/Downloads/arduino-1.8.5-linux64/arduino-1.8.5/hardware/tools/avr/bin/avr-g++" -c -g -Os -w -std=gnu++11 -fpermissive -fno-exceptions -ffunction-sections -fdata-sections -fno-threadsafe-statics  -flto -w -x c++ -E -CC -mmcu=atmega32u4 -DF_CPU=16000000L -DARDUINO=10805 -DARDUINO_AVR_LEONARDO -DARDUINO_ARCH_AVR  -DUSB_VID=0x2341 -DUSB_PID=0x8036 '-DUSB_MANUFACTURER="Unknown"' '-DUSB_PRODUCT="Arduino Leonardo"' "-I/home/xx/Downloads/arduino-1.8.5-linux64/arduino-1.8.5/hardware/arduino/avr/cores/arduino" "-I/home/xx/Downloads/arduino-1.8.5-linux64/arduino-1.8.5/hardware/arduino/avr/variants/leonardo" "/tmp/arduino_build_936373/sketch/IRKit.ino.cpp" -o "/dev/null"
"/home/xx/Downloads/arduino-1.8.5-linux64/arduino-1.8.5/hardware/tools/avr/bin/avr-g++" -c -g -Os -w -std=gnu++11 -fpermissive -fno-exceptions -ffunction-sections -fdata-sections -fno-threadsafe-statics  -flto -w -x c++ -E -CC -mmcu=atmega32u4 -DF_CPU=16000000L -DARDUINO=10805 -DARDUINO_AVR_LEONARDO -DARDUINO_ARCH_AVR  -DUSB_VID=0x2341 -DUSB_PID=0x8036 '-DUSB_MANUFACTURER="Unknown"' '-DUSB_PRODUCT="Arduino Leonardo"' "-I/home/xx/Downloads/arduino-1.8.5-linux64/arduino-1.8.5/hardware/arduino/avr/cores/arduino" "-I/home/xx/Downloads/arduino-1.8.5-linux64/arduino-1.8.5/hardware/arduino/avr/variants/leonardo" "/tmp/arduino_build_936373/sketch/CRC8.c" -o "/dev/null"
"/home/xx/Downloads/arduino-1.8.5-linux64/arduino-1.8.5/hardware/tools/avr/bin/avr-g++" -c -g -Os -w -std=gnu++11 -fpermissive -fno-exceptions -ffunction-sections -fdata-sections -fno-threadsafe-statics  -flto -w -x c++ -E -CC -mmcu=atmega32u4 -DF_CPU=16000000L -DARDUINO=10805 -DARDUINO_AVR_LEONARDO -DARDUINO_ARCH_AVR  -DUSB_VID=0x2341 -DUSB_PID=0x8036 '-DUSB_MANUFACTURER="Unknown"' '-DUSB_PRODUCT="Arduino Leonardo"' "-I/home/xx/Downloads/arduino-1.8.5-linux64/arduino-1.8.5/hardware/arduino/avr/cores/arduino" "-I/home/xx/Downloads/arduino-1.8.5-linux64/arduino-1.8.5/hardware/arduino/avr/variants/leonardo" "/tmp/arduino_build_936373/sketch/FullColorLed.cpp" -o "/dev/null"
"/home/xx/Downloads/arduino-1.8.5-linux64/arduino-1.8.5/hardware/tools/avr/bin/avr-g++" -c -g -Os -w -std=gnu++11 -fpermissive -fno-exceptions -ffunction-sections -fdata-sections -fno-threadsafe-statics  -flto -w -x c++ -E -CC -mmcu=atmega32u4 -DF_CPU=16000000L -DARDUINO=10805 -DARDUINO_AVR_LEONARDO -DARDUINO_ARCH_AVR  -DUSB_VID=0x2341 -DUSB_PID=0x8036 '-DUSB_MANUFACTURER="Unknown"' '-DUSB_PRODUCT="Arduino Leonardo"' "-I/home/xx/Downloads/arduino-1.8.5-linux64/arduino-1.8.5/hardware/arduino/avr/cores/arduino" "-I/home/xx/Downloads/arduino-1.8.5-linux64/arduino-1.8.5/hardware/arduino/avr/variants/leonardo" "/tmp/arduino_build_936373/sketch/GSwifi.cpp" -o "/dev/null"
"/home/xx/Downloads/arduino-1.8.5-linux64/arduino-1.8.5/hardware/tools/avr/bin/avr-g++" -c -g -Os -w -std=gnu++11 -fpermissive -fno-exceptions -ffunction-sections -fdata-sections -fno-threadsafe-statics  -flto -w -x c++ -E -CC -mmcu=atmega32u4 -DF_CPU=16000000L -DARDUINO=10805 -DARDUINO_AVR_LEONARDO -DARDUINO_ARCH_AVR  -DUSB_VID=0x2341 -DUSB_PID=0x8036 '-DUSB_MANUFACTURER="Unknown"' '-DUSB_PRODUCT="Arduino Leonardo"' "-I/home/xx/Downloads/arduino-1.8.5-linux64/arduino-1.8.5/hardware/arduino/avr/cores/arduino" "-I/home/xx/Downloads/arduino-1.8.5-linux64/arduino-1.8.5/hardware/arduino/avr/variants/leonardo" "/tmp/arduino_build_936373/sketch/HardwareSerialX.cpp" -o "/dev/null"
"/home/xx/Downloads/arduino-1.8.5-linux64/arduino-1.8.5/hardware/tools/avr/bin/avr-g++" -c -g -Os -w -std=gnu++11 -fpermissive -fno-exceptions -ffunction-sections -fdata-sections -fno-threadsafe-statics  -flto -w -x c++ -E -CC -mmcu=atmega32u4 -DF_CPU=16000000L -DARDUINO=10805 -DARDUINO_AVR_LEONARDO -DARDUINO_ARCH_AVR  -DUSB_VID=0x2341 -DUSB_PID=0x8036 '-DUSB_MANUFACTURER="Unknown"' '-DUSB_PRODUCT="Arduino Leonardo"' "-I/home/xx/Downloads/arduino-1.8.5-linux64/arduino-1.8.5/hardware/arduino/avr/cores/arduino" "-I/home/xx/Downloads/arduino-1.8.5-linux64/arduino-1.8.5/hardware/arduino/avr/variants/leonardo" "/tmp/arduino_build_936373/sketch/IRKitHTTPHandler.cpp" -o "/dev/null"
"/home/xx/Downloads/arduino-1.8.5-linux64/arduino-1.8.5/hardware/tools/avr/bin/avr-g++" -c -g -Os -w -std=gnu++11 -fpermissive -fno-exceptions -ffunction-sections -fdata-sections -fno-threadsafe-statics  -flto -w -x c++ -E -CC -mmcu=atmega32u4 -DF_CPU=16000000L -DARDUINO=10805 -DARDUINO_AVR_LEONARDO -DARDUINO_ARCH_AVR  -DUSB_VID=0x2341 -DUSB_PID=0x8036 '-DUSB_MANUFACTURER="Unknown"' '-DUSB_PRODUCT="Arduino Leonardo"' "-I/home/xx/Downloads/arduino-1.8.5-linux64/arduino-1.8.5/hardware/arduino/avr/cores/arduino" "-I/home/xx/Downloads/arduino-1.8.5-linux64/arduino-1.8.5/hardware/arduino/avr/variants/leonardo" "/tmp/arduino_build_936373/sketch/IRKitJSONParser.c" -o "/dev/null"
"/home/xx/Downloads/arduino-1.8.5-linux64/arduino-1.8.5/hardware/tools/avr/bin/avr-g++" -c -g -Os -w -std=gnu++11 -fpermissive -fno-exceptions -ffunction-sections -fdata-sections -fno-threadsafe-statics  -flto -w -x c++ -E -CC -mmcu=atmega32u4 -DF_CPU=16000000L -DARDUINO=10805 -DARDUINO_AVR_LEONARDO -DARDUINO_ARCH_AVR  -DUSB_VID=0x2341 -DUSB_PID=0x8036 '-DUSB_MANUFACTURER="Unknown"' '-DUSB_PRODUCT="Arduino Leonardo"' "-I/home/xx/Downloads/arduino-1.8.5-linux64/arduino-1.8.5/hardware/arduino/avr/cores/arduino" "-I/home/xx/Downloads/arduino-1.8.5-linux64/arduino-1.8.5/hardware/arduino/avr/variants/leonardo" "/tmp/arduino_build_936373/sketch/IrCtrl.cpp" -o "/dev/null"
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
domier, 2017-12-17:
OK, I seem to have resolved that problem by updating cert.h to match your most recent version:

https://github.com/acourreges/device/compare/settings-led-cloud...domier:settings-led-cloud

Now I'm getting this error, which I also get when trying to flash the official firmware.  Any idea how to resolve it?:

Arduino: 1.8.5 (Linux), Board: "Arduino Leonardo"

In file included from /home/xx/Downloads/irkit firmware/device-settings-led-cloud/firmware/src/IRKit/IRKit.ino:22:0:
sketch/pgmStrToRAM.h:29:33: warning: '__progmem__' attribute ignored [-Wattributes]
 char *pgmStrToRAM(PROGMEM char *theString, uint8_t index);
                                 ^
In file included from sketch/GSwifi.h:30:0,
                 from /home/xx/Downloads/irkit firmware/device-settings-led-cloud/firmware/src/IRKit/IRKit.ino:26:
sketch/ringbuffer.h:34:23: warning: inline function 'void ring_init(volatile RingBuffer*, volatile char*, uint8_t)' used but never defined
 extern inline void    ring_init    (volatile struct RingBuffer *ring, volatile char *area, uint8_t size);
                       ^
sketch/ringbuffer.h:35:23: warning: inline function 'int8_t ring_put(volatile RingBuffer*, char)' used but never defined
 extern inline int8_t  ring_put     (volatile struct RingBuffer *ring, char dat);
                       ^
sketch/ringbuffer.h:38:23: warning: inline function 'uint8_t ring_isempty(volatile RingBuffer*)' used but never defined
 extern inline uint8_t ring_isempty (volatile struct RingBuffer *ring);
                       ^
sketch/ringbuffer.h:36:23: warning: inline function 'uint8_t ring_get(volatile RingBuffer*, char*, uint8_t)' used but never defined
 extern inline uint8_t ring_get     (volatile struct RingBuffer *ring, char *dat, uint8_t len);
                       ^
Sketch uses 25040 bytes (87%) of program storage space. Maximum is 28672 bytes.
Global variables use 2227 bytes (86%) of dynamic memory, leaving 333 bytes for local variables. Maximum is 2560 bytes.
Low memory available, stability problems may occur.

avrdude: butterfly_recv(): programmer is not responding
avrdude: butterfly_recv(): programmer is not responding
avrdude: butterfly_recv(): programmer is not responding
avrdude: butterfly_recv(): programmer is not responding
avrdude: butterfly_recv(): programmer is not responding
Found programmer: Id = ""; type =
    Software Version =  . ; Hardware Version = �.�
avrdude: butterfly_recv(): programmer is not responding
avrdude: butterfly_recv(): programmer is not responding
avrdude: error: buffered memory access not supported. Maybe it isn't
a butterfly/AVR109 but a AVR910 device?
avrdude: initialization failed, rc=-1
         Double check connections and try again, or use -F to override
         this check.

avrdude: butterfly_recv(): programmer is not responding
avrdude: error: programmer did not respond to command: leave prog mode
avrdude: butterfly_recv(): programmer is not responding
avrdude: error: programmer did not respond to command: exit bootloader
avrdude: error: programmer did not respond to command: exit bootloader

This report would have more information with
"Show verbose output during compilation"
option enabled in File -> Preferences.

domier, 2017-12-17:
It looks like I'm having a driver issue... can't get the computer to see the irkit in Windows or in Ubuntu.  I'll have to create a mac VM over the holidays and see if I can get it to work...

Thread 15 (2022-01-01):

Online order

BrechtSerckx, 2022-01-01:
Hi, can IRKit be bought online these days? It's not available on Switch-Science anymore it seems.

mash, 2022-01-01:
Sorry it’s not available anywhere anymore.

On Sat, 1. Jan 2022 at 19:21, Brecht Serckx ***@***.***>
wrote:

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

BrechtSerckx, 2022-01-01:
That's a pity. It's a very interesting project, but I lack the technical skills and time to reproduce myself.

ich777, 2022-07-23:
@mash I know that you are not selling IRKits anymore but is it basically possible to order the PCB from jlcpcb.com and let them assemble everything, is there something else needed?
Are only the Gerber files named `IRKit` and the `IRKit.partlist.csv` needed or are there any necessary parts/components needed?

mash, 2022-07-24:
I do not recomment to go that route. It's almost impossible to get a Gainspan Wi-Fi module, part no. GS1011MEPS and write the firmware with the same version (s2w-2_5_1) into it(I don't think I should redistribute it). Other parts should have equivalents.

Maybe try to fork this repo and use a newer and widely used Wi-Fi module, like ESP32 from Espressif. There are Arduino projects out there using ESP32.

ich777, 2022-07-24:
Okay, I've found a few projects but they are actually pretty hard to get over here where I live...

I've also found a few Tuya based devices that you can flash so that you can use MQTT to integrate it in your Home Automation or whatever but IRKit was pretty unique and I really liked it with the way how commands are sent/received...

Have to dig a little deeper, thank you for your response!

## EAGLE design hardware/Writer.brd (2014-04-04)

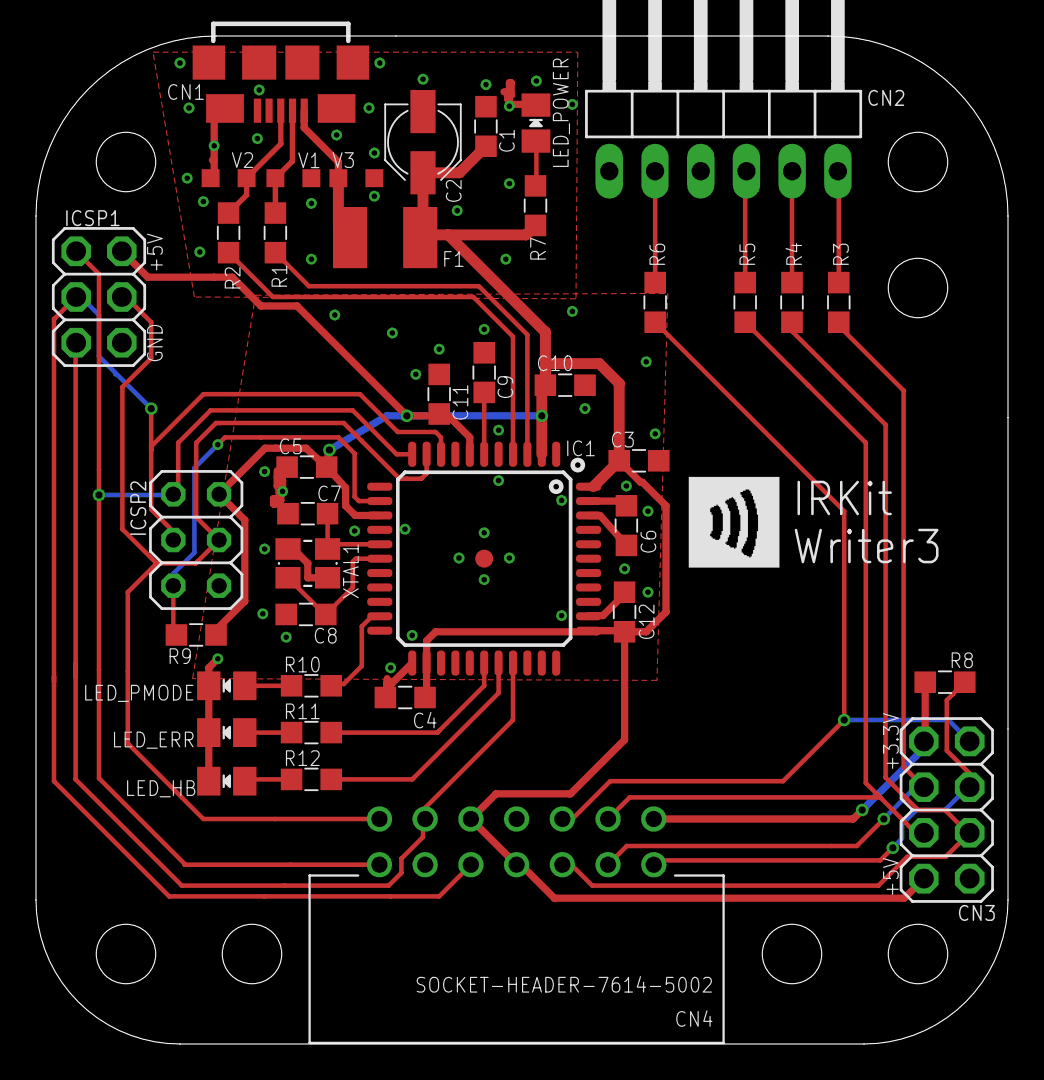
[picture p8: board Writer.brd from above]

Board: 2 copper layers, 54.0 x 56.0 mm, 52 parts (0 on the bottom side), 33 nets.

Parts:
C1, C3, C4, C5, C6, C10, C11, C12: 0.1uF; SMD2012
C2: 10uF; PANASONIC_B
C7, C8: 12pF; SMD2012
C9: 1uF; SMD2012
CN1: ZX62-B-5PA(11); USB-MICROB
CN2: TTL-232R-3V3; 1X06/90
CN3: WiFi-Header; 2X04/D1.1
CN4: SOCKET-HEADER-7614-5002
F1: MF-MSMF075-2; L1812
IC1: ATMEGA32U4AU; TQFP44-PAD
ICSP1: IRKit ICSP; 2X03/D1.1
ICSP2: Writer ICSP; 2X03
LED_ERR: LED2012
LED_HB: LED2012
LED_PMODE: LED2012
LED_POWER: OSG50805C1C; LED2012
R1, R2: 22; SMD2012
R3, R4, R5, R6, R8: 1k; SMD2012
R7, R10, R11, R12: 5.1k; SMD2012
R9: 10k; SMD2012
SCREW1, SCREW2, SCREW3, SCREW4: flat-head M3 self-tapping; SCREW-M3
STANDOFF1, STANDOFF2, STANDOFF3, STANDOFF4, STANDOFF5, STANDOFF6, STANDOFF7: STAND-OFF
U$1: IRKIT-LOGO
V1, V2, V3: CG0603MLC-05E; CT/CN0603
XTAL1: 16MHz CL:10pF; CRYSTAL-3.2-2.5

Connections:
+3V3: CN3.1, CN4.2, R8.2
+5V: C1.1, C2.+, C3.2, C4.2, C5.2, C10.2, C11.2, C12.2, CN3.7, CN4.7, CN4.10, F1.2, IC1.2, IC1.7, IC1.14, IC1.24, IC1.34, IC1.44, ICSP1.2, ICSP2.2, R7.1, R9.2
AREF: C6.2, IC1.42
CTS#: CN2.2, R6.1
D1/LED_PMODE: IC1.21, R10.1
D8/LED_ERR: IC1.28, R11.1
D9/LED_HB: IC1.29, R12.1
GND: C1.2, C2.-, C3.1, C4.1, C5.1, C6.1, C7.1, C8.1, C9.1, C10.1, C11.1, C12.1, CN1.P5, CN1.S1, CN1.S2, CN1.S3, CN1.S4, CN1.S5, CN1.S6, CN2.1, CN3.8, CN4.8, CN4.11, IC1.5, IC1.15, IC1.23, IC1.35, IC1.43, IC1.P$1, ICSP1.6, ICSP2.6, LED_ERR.K, LED_HB.K, LED_PMODE.K, LED_POWER.K, V1.2, V2.2, V3.2, XTAL1.2, XTAL1.4
IRKIT/!RESET: CN4.12, IC1.30, ICSP1.5
IRKIT/MISO: CN4.13, IC1.11, ICSP1.1, ICSP2.1
IRKIT/MOSI: CN4.14, IC1.10, ICSP1.4, ICSP2.4
IRKIT/SCK: CN4.9, IC1.9, ICSP1.3, ICSP2.3
unnamed: LED_PMODE.A, R10.2
unnamed: LED_ERR.A, R11.2
unnamed: LED_POWER.A, R7.2
unnamed: LED_HB.A, R12.2
unnamed: CN1.P2, R1.2, V1.1
unnamed: CN1.P3, R2.2, V2.1
unnamed: CN1.P1, F1.1, V3.1
RTS#: CN2.6, R3.1
RXD: CN2.5, R4.1
TXD: CN2.4, R5.1
UCAP: C9.2, IC1.6
USB+: IC1.4, R2.1
USB-: IC1.3, R1.1
WIFI_UART0_CTS: CN3.3, CN4.3, R3.2
WIFI_UART0_RTS: CN3.2, CN4.6, R6.2
WIFI_UART0_RX: CN3.5, CN4.4, R5.2
WIFI_UART0_TX: CN3.6, CN4.5, R4.2
WIFI_UART1_RTS: CN3.4, CN4.1, R8.1
WRITER/!RESET: IC1.13, ICSP2.5, R9.1
XTAL1: C8.2, IC1.17, XTAL1.1
XTAL2: C7.2, IC1.16, XTAL1.3

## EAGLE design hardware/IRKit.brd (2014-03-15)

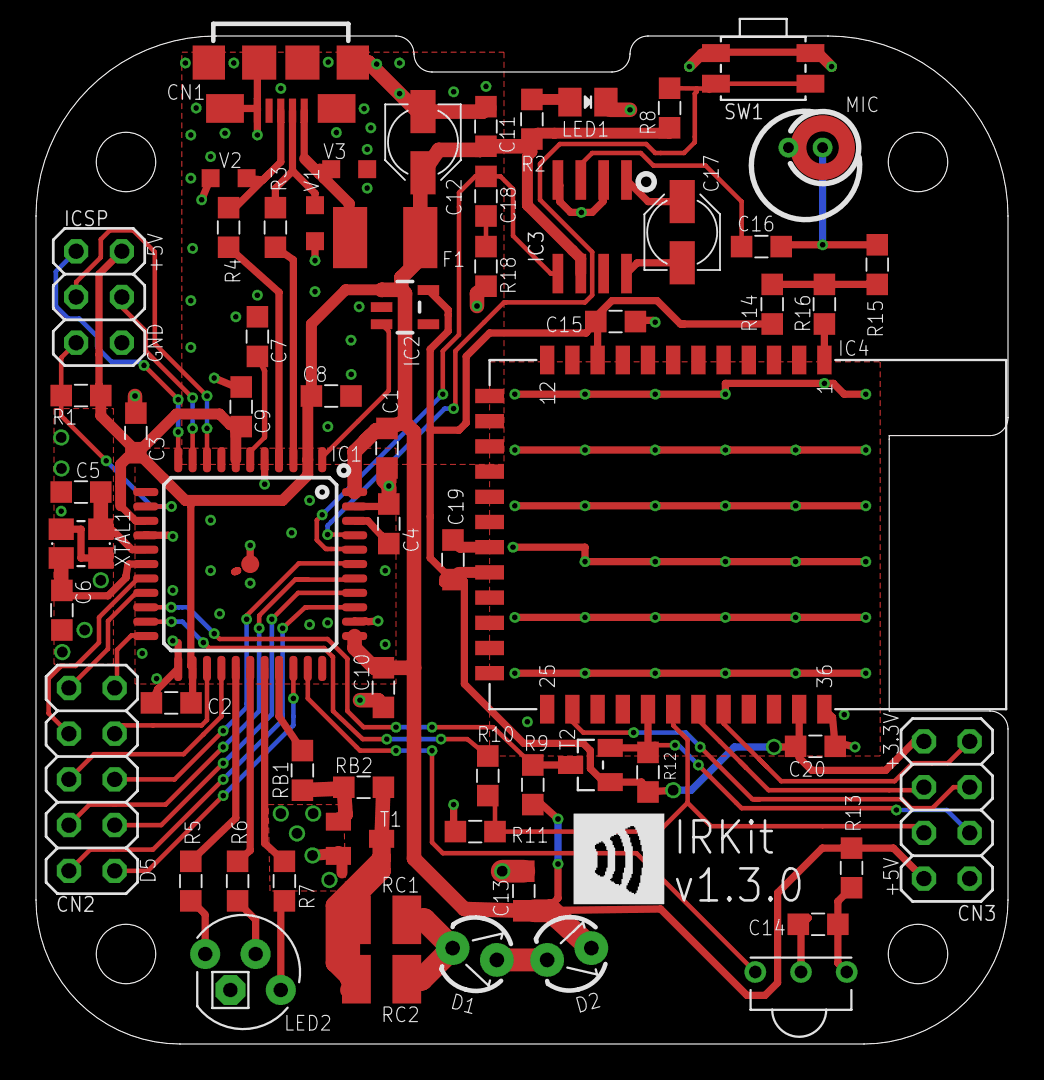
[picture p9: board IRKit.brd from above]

Board: 2 copper layers, 54.0 x 56.0 mm, 75 parts (0 on the bottom side), 56 nets.

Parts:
C1, C2, C3, C4, C8, C9, C10, C11, C15, C19, C20: 0.1uF; SMD2012
C5, C6: 12pF; SMD2012
C7, C16: 1uF; SMD2012
C12, C17: 10uF; PANASONIC_B
C13, C14: 4.7uF; SMD2012
C18: 0.047uF; SMD2012
CN1: ZX62-B-5PA(11); USB-MICROB
CN2: 2X05
CN3: 2X04
D1, D2: VSLB3940; LED3MM
F1: MF-MSMF075-2; L1812
IC1: ATMEGA32U4AU; TQFP44-PAD
IC2: TLV70233DBVT; SOT23-5
IC3: LM386M-1/NOPB; SO08
IC4: GS1011MXXS
ICSP: ICSP; 2X03
IR-RECEIVER: PL-IRM2161; IR-RECEIVER
LED1: PG1112H-TR; LED2012
LED2: 5MMRGBLED; LED5MMRGB
LEDCAP1: LED-CAP
MIC: 254-ECM6044-RO; MIC_SMD_4MM
R1, R9: 10k; SMD2012
R2, R6, R10, R15: 2.2k; SMD2012
R3, R4: 22; SMD2012
R5, R7, R11, R14: 3.3k; SMD2012
R8, R16: 5.1k; SMD2012
R12: 4.7k; SMD2012
R13: 220; SMD2012
R18: 10; SMD2012
RB1: 1.8k; SMD2012
RB2: 10k; SMD2012
RC1, RC2: 10Ω 0.5W; 3225
SCREW1, SCREW2, SCREW3, SCREW4: flat-head M3 self-tapping; SCREW-M3
SP1, SP2: LK-5; LED-SPACER-LK
STANDOFF1, STANDOFF2, STANDOFF3, STANDOFF4: STAND-OFF
SW1: EVQPUJ02K; TACTILE-SWITCH-EVQPUJ02K
T1: 2SD1781KT146Q; SC59-BEC
T2: BSS138; SOT23
U$1: IRKIT-LOGO
V1, V2, V3: CG0603MLC-05E; CT/CN0603
XTAL1: 16MHz CL:10pF; CRYSTAL-3.2-2.5

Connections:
!RESET: IC1.13, ICSP.5, R1.1
+2V: R14.1, R15.2, R16.2
+3V3: C15.2, C19.2, C20.2, CN3.1, IC2.5, IC4.10, IC4.20, IC4.35, R12.2, R14.2, T2.1
+5V: C1.2, C2.2, C3.2, C8.2, C9.2, C10.2, C11.1, C12.+, C13.1, CN3.7, D2.A, F1.2, IC1.2, IC1.7, IC1.14, IC1.24, IC1.34, IC1.44, IC2.1, IC3.6, ICSP.2, R1.2, R2.1, R8.1, R9.2, R13.2
A0: CN2.9, IC1.36
A1: CN2.8, IC1.37
A2: CN2.7, IC1.38
A3: CN2.6, IC1.39
A4/MIC: C18.1, IC1.40, IC3.5
A5/!RESET_SWITCH: IC1.41, R8.2, SW1.1, SW1.3
AREF: C4.2, IC1.42
D0/WIFIRX: IC1.20, R9.1, T2.3
D1/WIFITX: IC1.21, R10.2
D2: CN2.1, IC1.19
D3: CN2.3, IC1.18
D4: CN2.4, IC1.25
D5: CN2.10, IC1.31
D6/LED_R: IC1.27, R5.1
D7/LDO3.3_EN: IC1.1, IC2.3
D8/LED_B: IC1.28, R6.1
D9/LED_G: IC1.29, R7.1
D10/IROUT: IC1.30, RB1.2
D12: CN2.5, IC1.26
D13/IRIN: IC1.32, IR-RECEIVER.1
GND: C1.1, C2.1, C3.1, C4.1, C5.1, C6.1, C7.1, C8.1, C9.1, C10.1, C11.2, C12.-, C13.2, C14.2, C15.1, C19.1, C20.1, CN1.P5, CN1.S1, CN1.S2, CN1.S3, CN1.S4, CN1.S5, CN1.S6, CN3.8, IC1.5, IC1.15, IC1.23, IC1.35, IC1.43, IC1.P$1, IC2.2, IC3.2, IC3.4, IC4.1, IC4.19, IC4.36, ICSP.6, IR-RECEIVER.2, LED1.K, LED2.3, MIC.2, R11.1, R16.1, R18.2, SW1.2, SW1.4, T1.E, V1.2, V2.2, V3.2, XTAL1.2, XTAL1.4
IRLED: D1.K, RC1.2, RC2.2
MICOUT: C16.1, MIC.1, R15.1
MISO: IC1.11, ICSP.1
MOSI: IC1.10, ICSP.4
unnamed: C17.-, IC3.8
unnamed: LED1.A, R2.2
unnamed: C16.2, IC3.3
unnamed: LED2.1, R7.2
unnamed: C17.+, IC3.1
unnamed: RB1.1, RB2.1, T1.B
unnamed: RB2.2, RC1.1, RC2.1, T1.C
unnamed: C18.2, R18.1
unnamed: C14.1, IR-RECEIVER.3, R13.1
unnamed: LED2.2, R6.2
unnamed: LED2.4, R5.2
unnamed: CN1.P2, R3.2, V1.1
unnamed: CN1.P3, R4.2, V2.1
unnamed: CN1.P1, F1.1, V3.1
unnamed: D1.A, D2.K
SCK: IC1.9, ICSP.3
TXLED: CN2.2, IC1.22
UCAP: C7.2, IC1.6
USB+: IC1.4, R4.1
USB-: IC1.3, R3.1
WIFI_UART0_CTS: CN3.3, IC4.31
WIFI_UART0_RTS: CN3.2, IC4.32
WIFI_UART0_RX: CN3.5, IC4.30, R10.1, R11.2
WIFI_UART0_TX: CN3.6, IC4.29, R12.1, T2.2
WIFI_UART1_RTS: CN3.4, IC4.26
XTAL1: C6.2, IC1.17, XTAL1.1
XTAL2: C5.2, IC1.16, XTAL1.3

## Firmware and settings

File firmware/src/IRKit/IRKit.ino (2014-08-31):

/*
 Copyright (C) 2013-2014 Masakazu Ohtsuka
  
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
 You should have received a copy of the GNU General Public License
 along with this program.  If not, see <http://www.gnu.org/licenses/>.
*/
#include "Arduino.h"
#include <avr/wdt.h>
#include "pins.h"
#include "const.h"
#include "MemoryFree.h"
#include "pgmStrToRAM.h"
#include "IrCtrl.h"
#include "IrPacker.h"
#include "FullColorLed.h"
#include "GSwifi.h"
#include "Keys.h"
#include "timer.h"
#include "longpressbutton.h"
#include "IRKitHTTPHandler.h"
#include "commands.h"
#include "version.h"
#include "log.h"

static struct long_press_button_state_t long_press_button_state;
static volatile uint8_t reconnect_timer = TIMER_OFF;
static char commands_data[COMMAND_QUEUE_SIZE];
static FullColorLed color( FULLCOLOR_LED_R, FULLCOLOR_LED_G, FULLCOLOR_LED_B );

struct RingBuffer commands;
GSwifi gs(&Serial1X);
Keys keys;
volatile char sharedbuffer[ SHARED_BUFFER_SIZE ];

void setup() {
    Serial.begin(115200);

    // while ( ! Serial ) ;

    ring_init( &commands, commands_data, COMMAND_QUEUE_SIZE );

    //--- initialize timer

    timer_init( on_timer );
    timer_start( TIMER_INTERVAL );

    //--- initialize full color led

    pinMode(FULLCOLOR_LED_R, OUTPUT);
    pinMode(FULLCOLOR_LED_G, OUTPUT);
    pinMode(FULLCOLOR_LED_B, OUTPUT);
    color.setLedColor( 1, 0, 0, false ); // red: error

    //--- initialize long press button

    pinMode( CLEAR_BUTTON, INPUT );
    long_press_button_state.pin            = CLEAR_BUTTON;
    long_press_button_state.callback       = &long_pressed;
    long_press_button_state.threshold_time = 5;

    //--- initialize IR

    pinMode(IR_OUT,           OUTPUT);

    // pull-up
    pinMode(IR_IN,            INPUT);
    digitalWrite(IR_IN,       HIGH);

    IR_initialize( &on_ir_receive );

    //--- initialize Wifi

    pinMode(LDO33_ENABLE,     OUTPUT);
    wifi_hardware_reset();

    // add your own code here!!
}

void loop() {
    irkit_http_loop();

    if (TIMER_FIRED(reconnect_timer)) {
        TIMER_STOP(reconnect_timer);
        connect();
    }

    process_commands();

    gs.loop();

    IR_loop();

#ifdef DEBUG
    if (Serial.available()) {
        static uint8_t last_character = '0';
        static bool command_mode = false;
        last_character = Serial.read();

        MAINLOG_WRITE(last_character);
        MAINLOG_PRINTLN();

        /* if (last_character == 0x1B) { */
        /*     command_mode = ! command_mode; */
        /*     MAINLOG_PRINT("command_mode:"); MAINLOG_PRINTLN(command_mode); */
        /* } */
        /* if (command_mode) { */
        /*     Serial1X.write(last_character); */
        /* } */
        /* else if (last_character == 'd') { */
        /*     MAINLOG_PRINTLN(); */
        /*     keys.load(); */
        /*     keys.dump(); */

        /*     MAINLOG_PRINTLN(); */
        /*     gs.dump(); */

        /*     MAINLOG_PRINTLN(); */
        /*     IR_dump(); */
        /* } */
        /* else if (last_character == 'l') { */
        /*     long_pressed(); */
        /* } */
        /* else if (last_character == 'v') { */
        /*     MAINLOG_PRINT("v:"); MAINLOG_PRINTLN(version); */
        /* } */
        /* else if (last_character == 's') { */
        /*     keys.set(GSSECURITY_WPA2_PSK, */
        /*              PB("Rhodos",1), */
        /*              PB("aaaaaaaaaaaaa",2)); */
        /*     keys.setKey(P("5284CF0D43994784897ECAB3D9935498")); */
        /*     keys.save(); */
        /* } */
    }
#endif

    // add your own code here!!
}

void wifi_hardware_reset () {
    MAINLOG_PRINTLN("!E25");

    // UART line powers GS and pulls 3.3V line up to around 1.4V so GS won't reset without this
    Serial1X.end();

    digitalWrite( LDO33_ENABLE, LOW );
    delay( 1000 );
    digitalWrite( LDO33_ENABLE, HIGH );

    // wait til gs wakes up
    delay( 1000 );

    ring_put( &commands, COMMAND_SETUP );
}

void long_pressed() {
    color.setLedColor( 1, 0, 0, false ); // red: error

    keys.clear();
    keys.save();
    software_reset();
}

void process_commands() {
    while (! ring_isempty(&commands)) {
        char command;
        ring_get( &commands, &command, 1 );

        switch (command) {
        case COMMAND_POST_KEYS:
            irkit_httpclient_post_keys();
            break;
        case COMMAND_SETUP:
            irkit_http_init();
            gs.setup( &on_disconnect, &on_reset );

            // vv continues
        case COMMAND_CONNECT:
            connect();
            break;
        case COMMAND_CLOSE:
            ring_get( &commands, &command, 1 );
            gs.close(command);
            break;
        case COMMAND_START_POLLING:
            irkit_httpclient_start_polling( 0 );
            break;
        case COMMAND_POST_DOOR:
            irkit_httpclient_post_door();
            break;
        case COMMAND_SETREGDOMAIN:
            {
                char regdomain;
                ring_get( &commands, &regdomain, 1 );
                gs.setRegDomain( regdomain );
            }
            break;
        default:
            break;
        }
    }
}

void on_irkit_ready() {
    color.setLedColor( 0, 0, 1, false ); // blue: ready
}

void on_ir_receive() {
    MAINLOG_PRINTLN("i<");
#ifdef IRLOG
    IR_dump();
#endif
    if (IR_packedlength() > 0) {
        if (IR_looks_like_noise()) {
            IRLOG_PRINTLN("!E31");
            return;
        }
        int8_t cid = irkit_httpclient_post_messages();
        if (cid >= 0) {
            color.setLedColor( 0, 0, 1, true, 1 ); // received: blue blink for 1sec
        }
    }
}

void on_ir_xmit() {
    MAINLOG_PRINTLN("i>");
    color.setLedColor( 0, 0, 1, true, 1 ); // xmit: blue blink for 1sec
}

// inside ISR, be careful
void on_timer() {
    color.onTimer(); // 200msec blink

    irkit_http_on_timer();

    TIMER_TICK( reconnect_timer );

    gs.onTimer();

    IR_timer();

    long_press_button_ontimer( &long_press_button_state );
}

int8_t on_reset() {
    MAINLOG_PRINTLN("!E10");

    ring_put( &commands, COMMAND_SETUP );
    return 0;
}

int8_t on_disconnect() {
    MAINLOG_PRINTLN("!E11");

    ring_put( &commands, COMMAND_CONNECT );
    return 0;
}

void connect() {
    IR_state( IR_DISABLED );

    // load wifi credentials from EEPROM
    keys.load();

    if (keys.isWifiCredentialsSet()) {
        color.setLedColor( 0, 1, 0, true ); // green blink: connecting

        gs.join(keys.getSecurity(),
                keys.getSSID(),
                keys.getPassword());
    }

    if (gs.isJoined()) {
        color.setLedColor( 0, 1, 1, true ); // cyan blink: setting up

        keys.setWifiWasValid(true);
        keys.save();

        // start http server
        gs.listen();
    }

    if (gs.isListening()) {
        // start mDNS
        gs.setupMDNS();

        if (keys.isAPIKeySet() && ! keys.isValid()) {
            irkit_httpclient_post_door();
        }
        else if (keys.isValid()) {
            IR_state( IR_IDLE );
            ring_put( &commands, COMMAND_START_POLLING );
            on_irkit_ready();
        }
    }
    else {
        keys.dump();

        if (keys.wasWifiValid()) {
            // retry
            color.setLedColor( 1, 0, 0, false ); // red: error
            TIMER_START(reconnect_timer, 5);
        }
        else {
            keys.clear();
            color.setLedColor( 1, 0, 0, true ); // red blink: listening for POST /wifi
            gs.startLimitedAP();
            if (gs.isLimitedAP()) {
                gs.listen();
            }
        }
    }
}

void software_reset() {
    wdt_enable(WDTO_15MS);
    while (1) ;
}

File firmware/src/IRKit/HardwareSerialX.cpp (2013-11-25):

/*
  HardwareSerialX.cpp - Hardware serial library for Wiring
  Copyright (c) 2006 Nicholas Zambetti.  All right reserved.

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
  Modified 23 November 2006 by David A. Mellis
  Modified 28 September 2010 by Mark Sproul
  Modified 14 August 2012 by Alarus
  Modified Nov 2013 by mash
*/

#include <stdlib.h>
#include <stdio.h>
#include <string.h>
#include <inttypes.h>
#include "Arduino.h"
#include "wiring_private.h"
#include "HardwareSerialX.h"

/*
 * on ATmega8, the uart and its bits are not numbered, so there is no "TXC0"
 * definition.
 */
#if !defined(TXC0)
#if defined(TXC)
#define TXC0 TXC
#elif defined(TXC1)
// Some devices have uart1 but no uart0
#define TXC0 TXC1
#else
#error TXC0 not definable in HardwareSerial.h
#endif
#endif

#define RX_BUFFER_SIZE     64
#define TX_BUFFER_SIZE     64
#define XONOFF_HYSTERESIS   4
volatile static struct RingBuffer rx_buffer1;
volatile static char rx_buffer1_data[RX_BUFFER_SIZE + 1];
volatile static struct RingBuffer tx_buffer1;
volatile static char tx_buffer1_data[TX_BUFFER_SIZE + 1];

#define XON  0x11
#define XOFF 0x13
volatile static bool is_limiting = false;
volatile static bool send_xon    = false;
volatile static bool send_xoff   = false;

ISR(USART1_RX_vect)
{
  if (bit_is_clear(UCSR1A, UPE1)) {
    unsigned char c = UDR1;
    if ( !ring_isfull( &rx_buffer1 ) ) {
      ring_put( &rx_buffer1, c );
    }

    if (! is_limiting &&
        ring_used( &rx_buffer1 ) > (RX_BUFFER_SIZE - XONOFF_HYSTERESIS)) {
      // limit if we're going to reach full soon
      is_limiting = true;
      if (bit_is_set(UCSR1A, UDRE1)) {
        // if USART Data Register Empty is 1, send immediately
        UDR1 = XOFF;
      }
      else {
        // if not empty, send on next interrupt
        send_xoff = true;
        sbi(UCSR1B, UDRIE1);
      }
    }

  } else {
    unsigned char c = UDR1;
  }
}

ISR(USART1_UDRE_vect)
{
  // actually send xon/xoff
  if (send_xoff) {
    send_xoff = false;
    UDR1      = XOFF;
    return;
  }
  if (send_xon) {
    send_xon = false;
    UDR1     = XON;
    return;
  }
  if (ring_isempty( &tx_buffer1 )) {
    // Buffer empty, so disable interrupts
    cbi(UCSR1B, UDRIE1);
  }
  else {
    // There is more data in the output buffer. Send the next byte
    char c;
    ring_get( &tx_buffer1, &c, 1 );
    UDR1 = c;
  }
}

// Constructors ////////////////////////////////////////////////////////////////

HardwareSerialX::HardwareSerialX(volatile RingBuffer *rx_buffer, volatile RingBuffer *tx_buffer,
  volatile uint8_t *ubrrh, volatile uint8_t *ubrrl,
  volatile uint8_t *ucsra, volatile uint8_t *ucsrb,
  volatile uint8_t *ucsrc, volatile uint8_t *udr,
  uint8_t rxen, uint8_t txen, uint8_t rxcie, uint8_t udrie, uint8_t u2x)
{
  ring_init( &rx_buffer1, rx_buffer1_data, RX_BUFFER_SIZE + 1 );
  ring_init( &tx_buffer1, tx_buffer1_data, TX_BUFFER_SIZE + 1 );

  _rx_buffer = rx_buffer;
  _tx_buffer = tx_buffer;
  _ubrrh = ubrrh;
  _ubrrl = ubrrl;
  _ucsra = ucsra;
  _ucsrb = ucsrb;
  _ucsrc = ucsrc;
  _udr = udr;
  _rxen = rxen;
  _txen = txen;
  _rxcie = rxcie;
  _udrie = udrie;
  _u2x = u2x;
}

// Public Methods //////////////////////////////////////////////////////////////

void HardwareSerialX::begin(unsigned long baud)
{
  uint16_t baud_setting;
  bool use_u2x = true;

#if F_CPU == 16000000UL
  // hardcoded exception for compatibility with the bootloader shipped
  // with the Duemilanove and previous boards and the firmware on the 8U2
  // on the Uno and Mega 2560.
  if (baud == 57600) {
    use_u2x = false;
  }
#endif

try_again:

  if (use_u2x) {
    *_ucsra = 1 << _u2x;
    baud_setting = (F_CPU / 4 / baud - 1) / 2;
  } else {
    *_ucsra = 0;
    baud_setting = (F_CPU / 8 / baud - 1) / 2;
  }

  if ((baud_setting > 4095) && use_u2x)
  {
    use_u2x = false;
    goto try_again;
  }

  // assign the baud_setting, a.k.a. ubbr (USART Baud Rate Register)
  *_ubrrh = baud_setting >> 8;
  *_ubrrl = baud_setting;

  transmitting = false;

  sbi(*_ucsrb, _rxen);
  sbi(*_ucsrb, _txen);
  sbi(*_ucsrb, _rxcie);
  cbi(*_ucsrb, _udrie);
}

void HardwareSerialX::begin(unsigned long baud, byte config)
{
  uint16_t baud_setting;
  uint8_t current_config;
  bool use_u2x = true;

#if F_CPU == 16000000UL
  // hardcoded exception for compatibility with the bootloader shipped
  // with the Duemilanove and previous boards and the firmware on the 8U2
  // on the Uno and Mega 2560.
  if (baud == 57600) {
    use_u2x = false;
  }
#endif
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

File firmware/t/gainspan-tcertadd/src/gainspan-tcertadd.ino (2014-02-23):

#include "Arduino.h"
#include "pins.h"
#include "pgmStrToRAM.h"
#include "HardwareSerialX.h"

#define ESCAPE      0x1B

#define CERT_LENGTH 753

prog_uchar der[] PROGMEM = {
    ESCAPE, 'W',
    0x30, 0x82, 0x2, 0xed, 0x30, 0x82, 0x2, 0x56,
    0xa0, 0x3, 0x2, 0x1, 0x2, 0x2, 0x9, 0x0,
    0xe7, 0x28, 0x2, 0x22, 0xa1, 0xf9, 0x3c, 0x5b,
    0x30, 0xd, 0x6, 0x9, 0x2a, 0x86, 0x48, 0x86,
    0xf7, 0xd, 0x1, 0x1, 0x5, 0x5, 0x0, 0x30,
    0x58, 0x31, 0xb, 0x30, 0x9, 0x6, 0x3, 0x55,
    0x4, 0x6, 0x13, 0x2, 0x4a, 0x50, 0x31, 0x11,
    0x30, 0xf, 0x6, 0x3, 0x55, 0x4, 0x8, 0x13,
    0x8, 0x4b, 0x61, 0x6e, 0x61, 0x67, 0x61, 0x77,
    0x61, 0x31, 0x12, 0x30, 0x10, 0x6, 0x3, 0x55,
    0x4, 0xa, 0x13, 0x9, 0x6d, 0x61, 0x61, 0x61,
    0x73, 0x68, 0x2e, 0x6a, 0x70, 0x31, 0xb, 0x30,
    0x9, 0x6, 0x3, 0x55, 0x4, 0xb, 0x13, 0x2,
    0x63, 0x61, 0x31, 0x15, 0x30, 0x13, 0x6, 0x3,
    0x55, 0x4, 0x3, 0x13, 0xc, 0x67, 0x65, 0x74,
    0x69, 0x72, 0x6b, 0x69, 0x74, 0x2e, 0x63, 0x6f,
    0x6d, 0x30, 0x20, 0x17, 0xd, 0x31, 0x34, 0x30,
    0x32, 0x32, 0x33, 0x30, 0x37, 0x30, 0x37, 0x31,
    0x34, 0x5a, 0x18, 0xf, 0x32, 0x30, 0x36, 0x34,
    0x30, 0x32, 0x31, 0x31, 0x30, 0x37, 0x30, 0x37,
    0x31, 0x34, 0x5a, 0x30, 0x58, 0x31, 0xb, 0x30,
    0x9, 0x6, 0x3, 0x55, 0x4, 0x6, 0x13, 0x2,
    0x4a, 0x50, 0x31, 0x11, 0x30, 0xf, 0x6, 0x3,
    0x55, 0x4, 0x8, 0x13, 0x8, 0x4b, 0x61, 0x6e,
    0x61, 0x67, 0x61, 0x77, 0x61, 0x31, 0x12, 0x30,
    0x10, 0x6, 0x3, 0x55, 0x4, 0xa, 0x13, 0x9,
    0x6d, 0x61, 0x61, 0x61, 0x73, 0x68, 0x2e, 0x6a,
    0x70, 0x31, 0xb, 0x30, 0x9, 0x6, 0x3, 0x55,
    0x4, 0xb, 0x13, 0x2, 0x63, 0x61, 0x31, 0x15,
    0x30, 0x13, 0x6, 0x3, 0x55, 0x4, 0x3, 0x13,
    0xc, 0x67, 0x65, 0x74, 0x69, 0x72, 0x6b, 0x69,
    0x74, 0x2e, 0x63, 0x6f, 0x6d, 0x30, 0x81, 0x9f,
    0x30, 0xd, 0x6, 0x9, 0x2a, 0x86, 0x48, 0x86,
    0xf7, 0xd, 0x1, 0x1, 0x1, 0x5, 0x0, 0x3,
    0x81, 0x8d, 0x0, 0x30, 0x81, 0x89, 0x2, 0x81,
    0x81, 0x0, 0xac, 0xca, 0x21, 0x93, 0xe0, 0x0,
    0xa8, 0xa5, 0x75, 0xbf, 0xd2, 0x2f, 0xad, 0xc8,
    0x74, 0xe0, 0x67, 0xfb, 0xbe, 0xa5, 0xba, 0x55,
    0xc9, 0x66, 0x58, 0xb1, 0xf, 0xe3, 0x96, 0xd9,
    0x38, 0xd, 0x52, 0x84, 0xcd, 0x70, 0x78, 0x4a,
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
};

void setup() {
    // USB serial
    Serial.begin(115200);

    // wait for connection
    while ( ! Serial ) ;

    pinMode( LDO33_ENABLE, OUTPUT );
    digitalWrite( LDO33_ENABLE, HIGH );

    // gainspan
    Serial1X.begin(57600);
}

void loop() {
    // gainspan -> usb
    if (Serial1X.available()) {
        Serial.write(Serial1X.read());
    }

    if (Serial.available()) {
        static uint8_t last_character = '0';
        static bool command_mode = false;
        last_character = Serial.read();

        Serial.write(last_character);
        // Serial.println();

        if (last_character == 0x1B) {
            command_mode = ! command_mode;
            Serial.print("command_mode:"); Serial.println(command_mode);
        }
        if (command_mode) {
            Serial1X.write(last_character);
        }
        else if (last_character == 't') {
            writeTCERTADD();
        }
        else if (last_character == 'w') {
            writeData();
        }
    }
}

void writeTCERTADD () {
    // Serial1X.println( "AT+TCERTADD=cacert,0,985,1" );
    Serial1X.print( "AT+TCERTADD=cacert,0," ); // 0: Binary format
    Serial1X.print( CERT_LENGTH );
    Serial1X.println( ",1" ); // 0: store in ram
}

void writeData () {
    /* for (uint16_t i=0; i<CERT_LENGTH; i++) { */
    /*     Serial1X.write( der[ i ] ); */
    /* } */
    for (uint16_t i=0; i<753 + 2; i++) {
        uint8_t read = pgm_read_byte_near(der + i);
        Serial1X.write( read );
        // Serial.write( read );
        Serial.print( read, HEX );
    }
}

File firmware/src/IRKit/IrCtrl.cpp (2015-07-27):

/*----------------------------------------------------------------------------/
/  IR_CTRL - IR remote control module                         (C)ChaN, 2008
/-----------------------------------------------------------------------------/
/ The IR_CTRL is a generic Transmisson/Reception control module for IR remote
/ control systems. This is a free software and is opened for education,
/ research and development under license policy of following trems.
/
/  Copyright (C) 2008, ChaN, all right reserved.
/  Copyright (C) 2013-, Masakazu Ohtsuka (mash), all right reserved.
/
/ * The IR_CTRL module is a free software and there is no warranty.
/ * You can use, modify and/or redistribute it for personal, non-profit or
/   commercial use without restriction under your responsibility.
/ * Redistributions of source code must retain the above copyright notice.
/
/-----------------------------------------------------------------------------/
/ Aug 30,'08 R0.01  First release.
/ May 16,'13 R0.    mash heavily modified everything
/----------------------------------------------------------------------------*/

#include <Arduino.h>
#include "IrCtrl.h"
#include "pgmStrToRAM.h"
#include "timer.h"
#include "IrPacker.h"
#include "env.h"
#include "const.h"
#include "log.h"

// avr/sfr_defs.h
#define _BV(bit) (1 << (bit))

/*----------------------------------------------------------------------------/
/ How this works (RX)
/-----------------------------------------------------------------------------/
/ When a change of the logic level occurs on Input Capture pin (ICP3)
/ and this edge conforms to Input Capture Edge Select (TCCR3B[ICES3]),
/ the 16bit value of the counter (TCNT3) is written to Input Capture Register (ICR3).
/ If Input Capture interrupt is enabled (ICIE3=1), ISR_CAPTURE() runs.
/ In ISR_CAPTURE(), we save interval of ICR3 since last edge
/ and toggle ICES3 to capture next edge
/ until the trailer (idle time without any edges) is detected.
/ see p119 of datasheet
/-----------------------------------------------------------------------------/
/ How this works (TX)
/-----------------------------------------------------------------------------/
/ We use Timer/Counter1's Fast PWM mode to generate IR carrier frequency(38kHz)
/ on Output Compare pin (OC1B).
/ 38kHz is determined by dividing our clock(16MHz) by 8 to make 2MHz, and counting 52 cycles.
/ Output Compare Register (OCR1A) is set to 52.
/ Provide an array of "Number of 2MHz cycles" in IrCtrl.buff .
/ Each entry of the array is set into Timer/Counter3's Output Compare Register (OCR3A),
/ which triggers an interrupt and run ISR_COMPARE() when compare matches.
/ In ISR_COMPARE(), we toggle ON/OFF of IR transmission (write 0/1 into TCCR1A[COM1B1])
/ and continue til the end of IrCtrl.buff .
/----------------------------------------------------------------------------*/

/*----------------------------------------------------------------------------/
/ Platform dependent definitions
/----------------------------------------------------------------------------*/
// Define interrupt service functions

// Rx: Timer input capture ISR
#define ISR_CAPTURE()   ISR(TIMER3_CAPT_vect)

// Timer compare match ISR
#define ISR_COMPARE()   ISR(TIMER3_COMPA_vect)

// --------------- RECV ---------------

// Initialize Timer3 for transmission/reception timing: Free running, clk/8
// TCCR3A : Timer/Counter3 Control Register A
//   0b00000000 = Normal port operation (don't output OC3[ABC] to any I/O pin)
// TCCR3B : Timer/Counter3 Control Register B
//   0bxxxxx001 = clk/   1
//   0bxxxxx010 = clk/   8 * 16MHz / 8 = 2MHz
//   0bxxxxx011 = clk/  64
//   0bxxxxx100 = clk/ 256
//   0bxxxxx110 = clk/1024
//   0b1xxxxxxx = Input Capture Noise Canceler: Active
//                Setting this bit (to one) activates the Input Capture Noise Canceler.
//                When the noise canceler is activated, the input from the Input Capture pin (ICP1)
//                is filtered. The filter function requires four successive equal valued samples of
//                the ICP1 pin for changing its output. The Input Capture is therefore delayed by
//                four Oscillator cycles when the noise canceler is enabled.
//   0bx0xxxxxx = Input Capture Edge Select
//                Toggle to detect rising/falling edge of ICP1 pin.
#define IR_INIT_TIMER() \
  TCCR3A = 0b00000000;  \
  TCCR3B = 0b10000010

// Check which edge generated the capture interrupt
// TCCR3B : Timer/Counter3 Control Register B
// ICES3 : Input Capture Edge Select
//   0 : falling (negative) edge is used as trigger
//   1 : rising (positive)  edge will trigger capture
// TIFR3 : Timer/Counter3 Interrupt Flag Register
// ICF3 : Timer/Counter3, Input Capture Flag
//   ICF3 can be cleared by writing a logic one to its bit location
// TOV3 : Timer/Counter3, Overflow Flag
// TIMSK3 : Timer/Counter3 Interrupt Mask Register
// ICIE3 : Timer/Counter3, Input Capture Interrupt Enable
//   When this bit is written to one,
//   and the I-flag in the Status Register is set (interrupts globally enabled),
//   the Timer/Counter3 Input Capture interrupt is enabled.
//   The corresponding Interrupt Vector (see “Interrupts” on page 57) is executed when the ICF3 Flag,
//   located in TIFR3, is set.
#define IR_CAPTURED_RISING() TCCR3B &   _BV(ICES3)
#define IR_CAPTURE_RISE()    TCCR3B |=  _BV(ICES3)
#define IR_CAPTURE_FALL()    TCCR3B &= ~_BV(ICES3)
#define IR_CAPTURE_ENABLE()  TIFR3  =   _BV(ICF3); TIMSK3 = _BV(ICIE3)
#define IR_CAPTURE_DISABLE() TIMSK3 &= ~_BV(ICIE3)   // Tx && Rx: Disable captureing interrupt

// ICR3 : Input Capture Register
#define IR_CAPTURE_REG()     ICR3

// --------------- XMIT ---------------

// Initialize Timer1 for IR subcarrier: Fast PWM, clk/8
// Countup from BOTTOM to TOP(=OCR1A), At BOTTOM set 1, At OCR1B set 0.
// "In fast PWM mode the counter is incremented until the counter value matches either one of the fixed values 0x00FF, 0x01FF, or 0x03FF (WGMn3:0 = 5, 6, or 7), the value in ICRn (WGMn3:0 = 14), or the value in OCRnA (WGMn3:0 = 15)." - we want the last behavior
// TCCR1A : Timer/Counter Control Register A
// TCCR1B : Timer/Counter Control Register B
//   0b010 : clk(T2S) / 8
// WGM10, WGM11, WGM12, WGM13 all 1 :
//   Timer/Counter Mode of Operation : Fast PWM - p148
//   TOP                             : OCRA
//   Update of OCRnX at              : TOP
//   TOV Flag Set on                 : TOP
// OCR1B : Timer/Counter1 Output Compare Register B
//   16 / 52 (OCR1A:38kHz) = 31% (PWM Duty)
#define IR_INIT_XMIT() \
  OCR1B  = 16; \
  TCCR1A = _BV(WGM11)|_BV(WGM10); \
  TCCR1B = _BV(WGM13)|_BV(WGM12)|0b010
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

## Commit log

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2013-06-07 ble112をリセットするためのS2スイッチをなくして、 AVRの!RESET(5V)を分圧して3V程度にしてからble112の!BLE/RSTにつなぐ これはFT232RLのDTRからつながってるからUSB通したシリアル通信をしようとするときに AVRのリセットと同時にble112もリセットするから AVRの起動後からble112とのシリアル通信がうまくいく (この変更を行うまでは,シリアル通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
    [iMote.brd, iMote.sch]
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2013-06-12 comments and logs
    Passkey Entry Failed (0x0301) でreadできない
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2013-06-19 shortcut to arduino directory
2013-06-19 fix and refine comments
    [IrCtrl.cpp]
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2013-07-03 no longer use unread status c12c update device name, manufacturer name, model number, appearance
2013-07-05 回路修正しました
    [iMote.brd, iMote.sch]
2013-07-11 回路修正_暫定版です
    [iMote.brd, iMote.sch]
2013-07-12 few fixes: * D2/BTN * D3/IROUT * D8/IRIN
    [iMote.brd, iMote.sch]
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2013-07-12 fix bug: sharp tv remote controller sends data which suffices (IrCtrl.len * 2 == msg->offset) and causes ir data receiving failure
    [IrCtrl.cpp]
2013-07-12 use less background straighter vcc shorter nets
    [iMote.brd, iMote.sch]
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2013-07-12 remove unused net this is v1.0!!!!
    [IRKit.brd, IRKit.sch]
2013-07-12 show pin name near connectors
    [IRKit.brd]
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2013-07-12 added partlist and synced with spreadsheet
    [IRKit.partlist.csv, imote.partlist.csv]
2013-07-16 added 3d model data for Rhinoceros3d
    [IRKit.3dm]
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2013-07-20 reset BLE112 from AVR
    [pins.h]
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2013-07-20 resistor values updated to that calculated in 4/Jul spreadsheet
    [IRKit.brd, IRKit.sch]
2013-07-23 refactored * values to pointers * use custom string error type to use type assertion in caller * use log.Print{f,ln} for logging, not fmt, to show file name and line numbers
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2013-07-26 add irkit_3model.3dm & irkit_3model.stl
    [IRKit.brd, IRKit.sch, irkit_3model.3dm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]
2013-07-26 changes the .3dm & .stl
    [irkit_3model.3dm, irkit_3model.stl]
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2013-08-05 when ios central reads auth status, and peripheral timeouts, ios crashes with multi thread problem, don't know a way to fix it, let's return 0 to continue..
2013-08-05 replace multibyte with html entity to pass appengine's internal filter
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2013-08-05 .sch & .brd & .3dm & .stl make a modification.
    [IRKit.brd, IRKit.sch, irkit_3model.3dm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]
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2013-08-08 temporary toggle to fix circuit's wrong wiring show green on clean startup
    [pins.h]
2013-08-08 this repo is for device related things only
    [irkit_3model.3dm, irkit_3model.stl]
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2013-08-09 fix beforeIRCallback (start fullcolor led blinking) timing
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2013-08-13 removed hole, and switch-cover for auth switch
    [IRKit.3dm]
2013-08-13 removed auth switch and related R
    [IRKit.brd, IRKit.sch]
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2013-08-29 move ref docs out
    [BLE112 Breakout Board v2.0.sch]
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2013-08-29 schematic for wifi with GS1011MXXS done, board not yet
    [IRKit.brd, IRKit.sch]
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2013-09-03 3dm moved to hardware/case
    [IRKit.3dm]
2013-09-03 extend board to 54x54 with R10 inner size of the case is 58x58 with R10, so we have 2mm margin
    [IRKit.brd]
2013-09-04 imported Sparkfun-Electromechanical library into my.lbr
    [IRKit.brd, IRKit.sch]
2013-09-04 adjusting parts positions to larger board size
    [IRKit.brd]
2013-09-04 brushing up board design
    [IRKit.brd, IRKit.sch]
2013-09-06 thanks to Mr. Katougi
    [IRKit.brd, IRKit.partlist.csv, IRKit.sch]
2013-09-06 move R,C out from atmega32u4's corner
    [IRKit.brd]
2013-09-07 2 holes for 2 IR LEDs
    [IRKit.3dm]
2013-09-07 fixed IR LED layout
    [IRKit.brd]
2013-09-07 silk fix
    [IRKit.brd, IRKit.sch]
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2013-09-13 updated case for 2 IR LEDs
    [IRKit.3dm]
2013-09-13 fillet, chamfer for bosses, holes
    [IRKit.3dm]
2013-09-13 make bottom side's taper upside down
    [IRKit.3dm]
2013-09-13 make dimension 1mm larger towards the usb micro connector
    [IRKit.brd]
2013-09-14 make IR LEDs closer
    [IRKit.brd, IRKit.sch]
2013-09-15 change shape of board near usb micro connector, so that the connector is more near to the case's connector hole
    [IRKit.brd]
2013-09-15 resized usb micro connector hole on the back side. can't make a fillet on the 4 edges of the usb connector hole, not enough Rhino skills...
    [IRKit.3dm]
2013-09-15 scrape a chase under the logo mark, to make the logo mark area's thickness flat
    [IRKit.3dm]
2013-09-16 wifi/atmega uart uses hardware serial
    [IRKit.brd, IRKit.sch]
2013-09-17 fix weird difference in 1 boss
    [IRKit.3dm]
2013-09-17 fix usb connector hole position
    [IRKit.3dm]
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2013-09-18 change the switch to EVQPUJ02K, to make the case's hole square and move top/bottom border downwards
    [IRKit.brd, IRKit.sch]
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2013-09-19 created a chase in the board's top-center, to let the case have a boss through there, to accurately position top/bottom parts
    [IRKit.brd]
2013-09-19 height fix!
    [IRKit.3dm]
2013-09-27 full color led's resistor value changed to that of last prototypes working value
    [IRKit.brd, IRKit.sch]
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2013-09-30 enlarge some pads of xtal, electrolytic capacitor more margin around F1
    [IRKit.brd, IRKit.sch]
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2013-10-04 fix schematic around microphone
    [IRKit.brd, IRKit.sch]
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2013-10-05 moved rgbled's library into my.lbr, fixed design rule check errors
    [IRKit.brd, IRKit.sch]
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2013-10-06 I think I can directly connect TTL-232R-3V3's pins to GS1011MIPS's UART pins
    [GS1011MWriter.brd, GS1011MWriter.sch]
2013-10-07 moved full color led and ir receiver inside 1mm, to avoid collision with screw bosses
    [IRKit.3dm, IRKit.brd, IRKit.sch]
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2013-10-07 changed C15 from electrolytic capacitor to ceramic capacitor
    [IRKit.brd, IRKit.sch]
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2013-10-09 added bypass capacitor near IR LEDs added varistor for Vusb
    [IRKit.brd, IRKit.sch]
2013-10-10 close loop around IR LEDs move silk away from vias
    [IRKit.brd, IRKit.sch]
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2013-10-10 crystal should use the exact recommended board pattern
    [IRKit.brd, IRKit.sch]
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2013-10-21 connect() works 115200bps is quite fast, too much debug output to serial might drop data from gs1011
    [GSwifi.cpp, gainspan-serial.ino, gainspan.ino]
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2013-10-23 fix led blinking bug
    [FullColorLed.cpp, led.ino]
2013-10-24 and 400, 404 error responses ok
    [GSwifi.cpp]
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2013-10-27 remove unused function small fixes to reduce program memory 24346
    [GSwifi.cpp]
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2013-10-30 C13 1uF -> 4.7uF 1uF couldn't stop atmega32u4 from resetting when sending IR
    [IRKit.brd, IRKit.sch]
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2013-10-31 use less program space, fix bugs
    28014
    [GSwifi.cpp]
2013-10-31 many improvements * issue AT+PSPOLLINTRL=0 command * re-setup and connect after GSwifi reboot
    [GSwifi.cpp]
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2013-11-01 updated usb connector pattern with hirose's recommended pattern
    [IRKit.brd, IRKit.sch]
2013-11-01 fixed DRC errors around MIC fatter lines around IR LED
    [IRKit.brd, IRKit.sch]
2013-11-01 tcp client and tcp server can coexist at the same time! (avoid "APP Reset-APP SW Reset" when using HTTP client)
    [GSwifi.cpp]
2013-11-01 resolve ip address before HTTP request
    [GSwifi.cpp]
2013-11-01 close CID after each request from us this (probably) prevents CID overflow
    [GSwifi.cpp]
2013-11-01 set mDNS hostname as IRKit%c%c where last 2 letters are of mac address. fix POST /door
    [GSwifi.cpp]
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2013-11-05 change R2,R8 value to 5.1k to reduce current
    [IRKit.brd, IRKit.sch]
2013-11-05 make lines around T1 thinner, because it took long to warm T1's emitter pad move R1 a little bit far from ICSP header, not to conflict with it
    [IRKit.brd]
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2013-11-05 added screws updated microphone input resistor value 2k -> 2.2k change voltage dividing resistors values 2k/3.3k -> 3.3k/5.1k
    [IRKit.brd, IRKit.partlist.csv, IRKit.sch]
2013-11-06 make drill more thicker for IR receiver, because it was not easy enough to insert. make GND plane's line width thiner, to make IR receiver's thermal thinner (it was hard to warm up)
    [IRKit.brd, IRKit.sch]
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2013-11-08 replace LM386MM-1 -> LM386M-1
    [IRKit.brd, IRKit.sch]
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2013-11-11 fix reconnect timer
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2013-11-11 hardware reset if any error occurs
    [GSwifi.cpp]
2013-11-11 bulk data receive was buggy, there's only * response data * request data * leftover either (ignore)
    [GSwifi.cpp]
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2013-11-11 move F1 downwards, to make more space between C12
    [IRKit.brd]
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2013-11-11 TCP_KEEPALIVE revival, wish this fixes bug that GS often turns into this error state which GS responds with ERROR only
    [GSwifi.cpp]
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2013-11-12 don't fail fatally on dnslookup failure, we cache our server's ipaddress anyway it happens randomly
    [GSwifi.cpp]
2013-11-12 we need to close our clientRequest before handling it. GS often locks when closing 2 connections in a row ex: POST /keys from iPhone (cid:1) -> POST /keys to server (cid:2) response from server arriv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
    [GSwifi.cpp]
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2013-11-12 do software reset too because hardware(low voltage) reset sometimes doesn't cause enough reset
    [GSwifi.cpp]
2013-11-12 shorter, but enough debug lines
    [GSwifi.cpp]
2013-11-14 retry using different wifi security for kindness * if wep(shared) failed, try open * if wpa2_psk failed, try wpa_psk
    [GSwifi.cpp]
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2013-11-25 using software flow control, to speed up UART baud rate from 38400 to 57600 (115200 seems unstable)
    [GSwifi.cpp, HardwareSerialX.cpp, IrCtrl.cpp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]
2013-11-26 use last 4 letters of macaddress, 2 might collide
    [GSwifi.cpp]
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2013-11-27 pinheader's drill to 0.85 (to fit conthrough of switch-science)
    [IRKit.brd, IRKit.sch]
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2013-11-28 replaced LED spacer to LK series package
    [IRKit.brd, IRKit.sch]
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2013-11-28 placed guide for text, dimension for IR hole
    [IRKit.3dm]
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2013-12-02 fixed dimension
    [IRKit.3dm]
2013-12-03 sometimes GS responds with "Serial2Wifi APP" after hardware reset, treat it like a usual :( app reset
    [GSwifi.cpp]
2013-12-05 if we have recently received GET /messages request, delay our next request to API server for a while to avoid concurrently processing receiving requests and requesting.
    suspend interval is set to 10sec, because iOS client's request timeout is 5sec,
    so 10sec is enough for client to re-issue another request and continue polling,
    while IRKit device stops requesting to api server
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2013-12-12 comments and error logs
    [GSwifi.cpp]
2013-12-13 fix bug that we started receiving IR data while transferring it to server
    [IrCtrl.cpp]
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2013-12-13 clear route_count_ on reset
    [GSwifi.cpp]
2013-12-14 ignore E14, it happens too much and no problem
    [IrCtrl.cpp]
2013-12-14 fix base64 encoder bug
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2013-12-17 fixed model to fit real world fixes
    [FactoryJig.3dm]
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2013-12-20 better error handling and logs preparing for factory-checker firmware POWER switch disconnects 5V and GND when turned off methods for factory checker test script follows main changes
    [Writer.brd, Writer.sch]
2013-12-20 fixed bug that content-length parse sometime fails
    [GSwifi.cpp]
2013-12-23 disable TCP_MAXRT and TCP_KEEPALIVE_X, because these commands takes some time to issue, and GS1011MIPS denies short TCP_KEEPALIVE_INTVL, and our server (currently Heroku) disconnects connections afte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
    [GSwifi.cpp]
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2013-12-23 fix irpacker_unpack_sequence for debugging
    [packer.ino]
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2013-12-24 fix led test
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2013-12-26 better error handling, colorled shouldn't show blue(ok) when not connected
    [GSwifi.cpp, IRKit.ino]
2013-12-26 make long button reset work faster
    [GSwifi.cpp, IRKit.ino]
2013-12-27 fix bug that crashes when unknown client connects and disconnects
    [GSwifi.cpp]
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2013-12-30 added stl to show visual on web github
    [IRKit.stl, irkit_3model.stl]
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2014-01-04 routes doesn't have to be reset
    [GSwifi.cpp, IRKit.ino]
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2014-01-19 when IRKit is repeatedly receiving noise IR signals, IRKit repeatedly POST agains internet server, on the same time, GET /m returns successfully, but next polling request (GET /m) 's AT+NCTCP fails w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
2014-01-19 don't setupMDNS if not listening, setupMDNS just does sends some commands, but all just fails
    [IRKit.ino]
2014-01-20 continous timeouts -> AVR software reset
    [GSwifi.cpp]
2014-01-20 GS software reset didn't work when we encountered "ERROR: SOCKET FAILURE 0" see https://gist.github.com/mash/080bd869d5bd10e90df5
2014-01-20 UART line powers GS and pulls 3.3V line up to around 1.4V, when UART TX is enabled (pulled up), so disable it before GS hardware reset
    [IRKit.ino]
2014-01-20 GSwifi can listen on non 0 cid, fixed bug that IRKit always resets after morse and join to wifi successfully finished. when we listen on 80 after join to infrastructure wifi, GS responds with CID: 1 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
    [GSwifi.cpp]
2014-01-20 short IR probably be noise reduce POST /p to internet server, to make IRKit more stable and internet server more light
    [IrCtrl.cpp]
2014-01-21 small fix re-render images
    [IRKit.sch]
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2014-02-06 shorter timeout for faster baud rate detection in factory setup
    [GSwifi.cpp]
2014-02-19 fix led test firmware
    [led.ino]
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2014-02-23 fix bug that POST body wasn't sent
    [GSwifi.cpp]
2014-02-25 tester doesn't do dnslookup, https
    [GSwifi.cpp]
2014-02-25 initialize server_cid to -1, to avoid software reset when not listening as server, and disconnecting cid=0
    [GSwifi.cpp]
2014-02-25 fix bug that tries to call unexisting callback
    [GSwifi.cpp]
2014-03-09 Fix bug: light remote controller AK-201 doesn't work.
    65535,0,XXXX sequence means:
    TX_OFF for 65535 + XXXX interval and turn TX_ON after that.
    Behaviour before bugfix was:
    TX_OFF for 65535 + 65535 + XXXX interval and turn TX_ON.
    [IrCtrl.cpp]
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2014-03-13 changed LED part no. to what I can buy in reel packaging
    [IRKit.brd, IRKit.partlist.csv, IRKit.sch]
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2014-03-17 fix bug that failed to join WEP security access point after using limitedAP
    [GSwifi.cpp]
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2014-04-04 added LED for ArduinoISP PMODE,ERR,HB. make ISP work on ATMEGA32U4.
    [Writer.brd, Writer.sch]
2014-04-04 make holes for IRKit ICSP and Wi-Fi header larger to fit pogopin diameter 1.02mm
    [Writer.brd, Writer.sch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]
2014-04-09 define another command to delay calling POST /d , to avoid deepening and overflowing stack
    [IRKit.ino, commands.h]
2014-05-08 When client request timeout happens, it takes a long time to wait til GS fixes it's own state. Let's not wait for it and just reset, to make ourself simpler.
    [GSwifi.cpp]
2014-05-12 Ignore whole IR signal if any of it's interval between rising/falling edges are shorter than threshold.
    [IRKit.ino, IrCtrl.cpp]
2014-08-27 Delay setregdomain to next loop, to avoid recursive call of command()
    [GSwifi.cpp, IRKit.ino, commands.h]
2014-08-27 Move big buffer to static, to avoid stack overflow. parseLine is not called recursively, so making buf static is safe.
    [GSwifi.cpp]
2014-08-27 close on next loop to avoid recursively calling ::command
    [GSwifi.cpp]
2014-08-29 noise-maker repeatedly transmits IR signals.
    [FullColorLed.cpp, GSwifi.cpp, IrCtrl.cpp]
2014-12-24 Fix gainspan test app
    [commands.h, gainspan.ino]
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2015-04-16 use Arduino-1.0.5 for less SRAM usage; see https://github.com/irkit/device/issues/9#issuecomment-89983746
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2015-07-27 Insert marker for password replacer
    [GSwifi.cpp]

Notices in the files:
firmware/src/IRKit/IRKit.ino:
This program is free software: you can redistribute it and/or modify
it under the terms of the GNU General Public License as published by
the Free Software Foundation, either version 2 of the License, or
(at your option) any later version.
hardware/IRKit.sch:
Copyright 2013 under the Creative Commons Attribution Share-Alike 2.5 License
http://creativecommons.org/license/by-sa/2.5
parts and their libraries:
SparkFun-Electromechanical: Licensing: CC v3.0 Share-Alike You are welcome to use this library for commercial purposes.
